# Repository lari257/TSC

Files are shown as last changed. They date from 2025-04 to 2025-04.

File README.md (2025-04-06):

### Florea Larisa - 333CA

# eBook Reader

## Diagrama Bloc

[Diagrama](https://www.mermaidchart.com/raw/8d10b74d-7767-4ccb-a096-3764c8156505?theme=light&version=v0.1&format=svg)

## Bill Of Materials (BOM)

| Part | Value | Device | Footprint Name | Detailed Description | CHECK_PRICES | DATASHEET |
|---|---|---|---|---|---|---|
| C1 | 4.7uF | EAGLE-LTSPICE_CC0402 | EAGLE-LTSPICE_C0402 | CAPACITOR, European symbol | [Link](https://ro.mouser.com/ProductDetail/EPCOS-TDK/B72520T0350K062?qs=dEfas%2FXlABIszF52uu7vrg%3D%3D) | nan |
| C1_BAT2 | 4.7uF | EAGLE-LTSPICE_CC0402 | EAGLE-LTSPICE_C0402 | CAPACITOR, European symbol | [Link](https://ro.mouser.com/ProductDetail/EPCOS-TDK/B72520T0350K062?qs=dEfas%2FXlABIszF52uu7vrg%3D%3D) | nan |
| C2 | 100nF | ESP32_WROVER_EAGLE-LTSPICE_CC0402 | ESP32_WROVER_EAGLE-LTSPICE_C0402 | CAPACITOR, European symbol | [Link](https://componentsearchengine.com/part-view/CC0402MRX5R5BB106/YAGEO) | nan |
| C2_BAT | 4.7uF | ESP32_WROVER_EAGLE-LTSPICE_CC0402 | ESP32_WROVER_EAGLE-LTSPICE_C0402 | CAPACITOR, European symbol | [Link](https://componentsearchengine.com/part-view/CC0402MRX5R5BB106/YAGEO) | nan |
| C3 | 100uF TANT | RCL_CPOL-EUCT3528 | RCL_CT3528 | POLARIZED CAPACITOR, European symbol | [Link](https://eu.mouser.com/ProductDetail/KYOCERA-AVX/F910J107MBAAJ6?qs=PqoDHHvF649LraCA%2FjeGXg%3D%3D) | [datasheet](https://ro.mouser.com/datasheet/2/40/F91_AJ6-3162641.pdf) |
| C4 | 4.7uF/25V | ESP32_WROVER_EAGLE-LTSPICE_CC0402 | ESP32_WROVER_EAGLE-LTSPICE_C0402 | CAPACITOR, European symbol | [Link](https://componentsearchengine.com/part-view/CC0402MRX5R5BB106/YAGEO) | nan |
| C4_USB | 100nF | ESP32_WROVER_EAGLE-LTSPICE_CC0402 | ESP32_WROVER_EAGLE-LTSPICE_C0402 | CAPACITOR, European symbol | [Link](https://componentsearchengine.com/part-view/CC0402MRX5R5BB106/YAGEO) | nan |
| C5 | 1uF | ESP32_WROVER_EAGLE-LTSPICE_CC0402 | ESP32_WROVER_EAGLE-LTSPICE_C0402 | CAPACITOR, European symbol | [Link](https://componentsearchengine.com/part-view/CC0402MRX5R5BB106/YAGEO) | nan |
| C5_USB | 4.7uF | ESP32_WROVER_EAGLE-LTSPICE_CC0402 | ESP32_WROVER_EAGLE-LTSPICE_C0402 | CAPACITOR, European symbol | [Link](https://componentsearchengine.com/part-view/CC0402MRX5R5BB106/YAGEO) | nan |
| C6 | 100nF | ESP32_WROVER_EAGLE-LTSPICE_CC0402 | ESP32_WROVER_EAGLE-LTSPICE_C0402 | CAPACITOR, European symbol | [Link](https://componentsearchengine.com/part-view/CC0402MRX5R5BB106/YAGEO) | nan |
| C7 | 10uF | ESP32_WROVER_EAGLE-LTSPICE_CC0402 | ESP32_WROVER_EAGLE-LTSPICE_C0402 | CAPACITOR, European symbol | [Link](https://componentsearchengine.com/part-view/CC0402MRX5R5BB106/YAGEO) | nan |
| C8 | 100nF | ESP32_WROVER_EAGLE-LTSPICE_CC0402 | ESP32_WROVER_EAGLE-LTSPICE_C0402 | CAPACITOR, European symbol | [Link](https://componentsearchengine.com/part-view/CC0402MRX5R5BB106/YAGEO) | nan |
| C9 | 100nF | EAGLE-LTSPICE_CC0402 | EAGLE-LTSPICE_C0402 | CAPACITOR, European symbol | [Link](https://ro.mouser.com/ProductDetail/EPCOS-TDK/B72520T0350K062?qs=dEfas%2FXlABIszF52uu7vrg%3D%3D) | nan |
| C10 | 100nF | ESP32_WROVER_EAGLE-LTSPICE_CC0402 | ESP32_WROVER_EAGLE-LTSPICE_C0402 | CAPACITOR, European symbol | [Link](https://componentsearchengine.com/part-view/CC0402MRX5R5BB106/YAGEO) | nan |
| C10_SUPERCAP | CPH3225A | CPH3225A | CAPCP3225X100N | Cap 0.011F 3.3V 1210 Flat Check availability | [Link](https://www.snapeda.com/parts/CPH3225A/Seiko+Instruments/view-part/?ref=eda) | [datasheet](https://www.snapeda.com/parts/CPH3225A/Seiko%20Instruments/datasheet/) |
| CHANGE_BUTTON| BUTTON_CUSYOMV1 | BUTTON_CUSYOMV1 | MYBUTTON | nan | [Link](https://industry.panasonic.com/global/en/products/control/switch/light-touch/number/evqpuj02k) | [datasheet](https://industry.panasonic.com/global/en/downloads?tab=catalog&small_g_cd=203&part_no=EVQPUJ02K) |
| CHG_LED | nan | ADAFRUIT_LEDCHIP-LED0603 | ADAFRUIT_CHIP-LED0603 | LED | [Link](https://www.snapeda.com/parts/KP-1608SURCK/Kingbright/view-part/?ref=eda) | [datasheet](https://www.snapeda.com/parts/KP-1608SURCK/Kingbright/datasheet/) |
| C_DELAY | 100nF | ESP32_WROVER_EAGLE-LTSPICE_CC0402 | ESP32_WROVER_EAGLE-LTSPICE_C0402 | CAPACITOR, European symbol | [Link](https://componentsearchengine.com/part-view/CC0402MRX5R5BB106/YAGEO) | nan |
| D1 | USBLC6-2SC6Y | USBLC6-2SC6Y | SOT95P280X145-6N | Low Cap. ESD Protection Auto SOT-23-6 STMicroelectronics USBLC6-2SC6Y, Dual Uni-Directional TVS Diode Array, 6-Pin SOT-23 | [Link](https://www.snapeda.com/parts/USBLC6-2SC6Y/STMicroelectronics/view-part/?ref=eda) | [datasheet](https://www.snapeda.com/parts/USBLC6-2SC6Y/STMicroelectronics/datasheet/) |
| D2 | ESP32_WROVER_AVX---SD0805S020S1R0_AVX_SD0805S020S1R0_0_0AVX_SD0805S020S1R0_0_0 | ESP32_WROVER_AVX---SD0805S020S1R0_AVX_SD0805S020S1R0_0_0AVX_SD0805S020S1R0_0_0 | ESP32_WROVER_AVX---SD0805S020S1R0_AVX_SD0805S020S1R0_0 | Schottky Barrier Rectifier Diode | [Link](https://eu.mouser.com/ProductDetail/KYOCERA-AVX/SD0805S020S1R0?qs=jCA%252BPfw4LHbpkAoSnwrdjw%3D%3D) | [datasheet](http://datasheets.avx.com/schottky.pdf) |
| D3 | MBR0530 | MBR0530 | SOD3716X135N | ON SEMICONDUCTOR - MBR0530 - DIODE, SCHOTTKY, 0.5A, 30V, SOD-123 | [Link](https://eu.mouser.com/ProductDetail/KYOCERA-AVX/SD0805S020S1R0?qs=jCA%252BPfw4LHbpkAoSnwrdjw%3D%3D) | [datasheet](https://ro.mouser.com/datasheet/2/40/schottky-3165252.pdf) |
| D4 | MBR0530 | MBR0530 | SOD3716X135N | ON SEMICONDUCTOR - MBR0530 - DIODE, SCHOTTKY, 0.5A, 30V, SOD-123 | [Link](https://www.snapeda.com/parts/MBR0530/Onsemi/view-part/?ref=eda) | [datasheet](https://www.snapeda.com/parts/MBR0530/ON%20Semiconductor/datasheet/) |
| D5 | MBR0530 | MBR0530 | SOD3716X135N | ON SEMICONDUCTOR - MBR0530 - DIODE, SCHOTTKY, 0.5A, 30V, SOD-123 | [Link](https://www.snapeda.com/parts/MBR0530/Onsemi/view-part/?ref=eda) | [datasheet](https://www.snapeda.com/parts/MBR0530/ON%20Semiconductor/datasheet/) |
| D6 | PGB1010603MR | PGB1010603MR | DIOC1608X36N | Check availability | [Link](https://www.snapeda.com/parts/PGB1010603MR/Littelfuse/view-part/?ref=eda) | [datasheet](https://www.snapeda.com/parts/PGB1010603MR/Littelfuse%20Inc./datasheet/) |
| D7 | ESP32_WROVER_AVX---SD0805S020S1R0_AVX_SD0805S020S1R0_0_0AVX_SD0805S020S1R0_0_0 | ESP32_WROVER_AVX---SD0805S020S1R0_AVX_SD0805S020S1R0_0_0AVX_SD0805S020S1R0_0_0 | ESP32_WROVER_AVX---SD0805S020S1R0_AVX_SD0805S020S1R0_0 | Schottky Barrier Rectifier Diode | [Link](https://eu.mouser.com/ProductDetail/KYOCERA-AVX/SD0805S020S1R0?qs=jCA%252BPfw4LHbpkAoSnwrdjw%3D%3D) | [datasheet](http://datasheets.avx.com/schottky.pdf) |
| D8 | PGB1010603MR | PGB1010603MR | DIOC1608X36N | Check availability | [Link](https://www.snapeda.com/parts/PGB1010603MR/Littelfuse/view-part/?ref=eda) | [datasheet](https://www.snapeda.com/parts/PGB1010603MR/Littelfuse%20Inc./datasheet/) |
| D9 | PGB1010603MR | PGB1010603MR | DIOC1608X36N | Check availability | [Link](https://www.snapeda.com/parts/PGB1010603MR/Littelfuse/view-part/?ref=eda) | [datasheet](https://www.snapeda.com/parts/PGB1010603MR/Littelfuse%20Inc./datasheet/) |
| D10 | PGB1010603MR | PGB1010603MR | DIOC1608X36N | Check availability | [Link](https://www.snapeda.com/parts/PGB1010603MR/Littelfuse/view-part/?ref=eda) | [datasheet](https://www.snapeda.com/parts/PGB1010603MR/Littelfuse%20Inc./datasheet/) |
| D11 | PGB1010603MR | PGB1010603MR | DIOC1608X36N | Check availability | [Link](https://www.snapeda.com/parts/PGB1010603MR/Littelfuse/view-part/?ref=eda) | [datasheet](https://www.snapeda.com/parts/PGB1010603MR/Littelfuse%20Inc./datasheet/) |
| D12 | PGB1010603MR | PGB1010603MR | DIOC1608X36N | Check availability | [Link](https://www.snapeda.com/parts/PGB1010603MR/Littelfuse/view-part/?ref=eda) | [datasheet](https://www.snapeda.com/parts/PGB1010603MR/Littelfuse%20Inc./datasheet/) |
| EPD_C1 | 1uF/50V | ESP32_WROVER_EAGLE-LTSPICE_CC0402 | ESP32_WROVER_EAGLE-LTSPICE_C0402 | CAPACITOR, European symbol | [Link](https://componentsearchengine.com/part-view/CC0402MRX5R5BB106/YAGEO) | [datasheet](http://datasheets.avx.com/schottky.pdf) |
| EPD_C2 | 1uF/50V | ESP32_WROVER_EAGLE-LTSPICE_CC0402 | ESP32_WROVER_EAGLE-LTSPICE_C0402 | CAPACITOR, European symbol | [Link](https://componentsearchengine.com/part-view/CC0402MRX5R5BB106/YAGEO) | [datasheet](http://datasheets.avx.com/schottky.pdf) |
| EPD_C5 | 1uF/50V | ESP32_WROVER_EAGLE-LTSPICE_CC0402 | ESP32_WROVER_EAGLE-LTSPICE_C0402 | CAPACITOR, European symbol | [Link](https://componentsearchengine.com/part-view/CC0402MRX5R5BB106/YAGEO) | [datasheet](http://datasheets.avx.com/schottky.pdf) |
| EPD_C6 | 1uF/50V | ESP32_WROVER_EAGLE-LTSPICE_CC0402 | ESP32_WROVER_EAGLE-LTSPICE_C0402 | CAPACITOR, European symbol | [Link](https://componentsearchengine.com/part-view/CC0402MRX5R5BB106/YAGEO) | [datasheet](http://datasheets.avx.com/schottky.pdf) |
| EPD_C7 | 1uF/50V | ESP32_WROVER_EAGLE-LTSPICE_CC0402 | ESP32_WROVER_EAGLE-LTSPICE_C0402 | CAPACITOR, European symbol | [Link](https://componentsearchengine.com/part-view/CC0402MRX5R5BB106/YAGEO) | [datasheet](http://datasheets.avx.com/schottky.pdf) |
| EPD_C8 | 1uF/50V | ESP32_WROVER_EAGLE-LTSPICE_CC0402 | ESP32_WROVER_EAGLE-LTSPICE_C0402 | CAPACITOR, European symbol | [Link](https://componentsearchengine.com/part-view/CC0402MRX5R5BB106/YAGEO) | [datasheet](http://datasheets.avx.com/schottky.pdf) |
| EPD_C9 | 1uF/50V | ESP32_WROVER_EAGLE-LTSPICE_CC0402 | ESP32_WROVER_EAGLE-LTSPICE_C0402 | CAPACITOR, European symbol | [Link](https://componentsearchengine.com/part-view/CC0402MRX5R5BB106/YAGEO) | [datasheet](http://datasheets.avx.com/schottky.pdf) |
| EPD_C10 | 1uF/50V | ESP32_WROVER_EAGLE-LTSPICE_CC0402 | ESP32_WROVER_EAGLE-LTSPICE_C0402 | CAPACITOR, European symbol | [Link](https://componentsearchengine.com/part-view/CC0402MRX5R5BB106/YAGEO) | [datasheet](http://datasheets.avx.com/schottky.pdf) |
| EPD_C11 | 1uF/50V | ESP32_WROVER_EAGLE-LTSPICE_CC0402 | ESP32_WROVER_EAGLE-LTSPICE_C0402 | CAPACITOR, European symbol | [Link](https://componentsearchengine.com/part-view/CC0402MRX5R5BB106/YAGEO) | [datasheet](http://datasheets.avx.com/schottky.pdf) |
| EPD_C12 | 1uF/50V | ESP32_WROVER_EAGLE-LTSPICE_CC0402 | ESP32_WROVER_EAGLE-LTSPICE_C0402 | CAPACITOR, European symbol | [Link](https://componentsearchengine.com/part-view/CC0402MRX5R5BB106/YAGEO) | [datasheet](http://datasheets.avx.com/schottky.pdf) |
| IC1 | BD5229G-TR | BD5229G-TR | SOT95P280X125-5N | Voltage Detector with Adjustable Delay Time: CMOS reset IC, low current consumption, Nch Open Drain and CMOS output types | [Link](https://componentsearchengine.com/part-view/BD5229G-TR/ROHM%20Semiconductor) | [datasheet](https://analytics.supplyframe.com/trackingservlet/track/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) |
| IC4 | XC6220A331MR-G | XC6220A331MR-G | SOT95P280X120-5N | LDO Voltage Regulators | [Link](https://componentsearchengine.com/part-view/XC6220A331MR-G/Torex) | [datasheet](https://analytics.supplyframe.com/trackingservlet/track/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) |
| J1 | FH34SRJ-24S-0.5SH_99_ | FH34SRJ-24S-0.5SH_99_ | FH34SRJ24S05SH99 | 24 Position FFC, FPC Connector Contacts, Top and Bottom 0.020 (0.50mm) Surface Mount, Right Angle | [Link](https://componentsearchengine.com/part-view/XC6220A331MR-G/Torex) | [datasheet](https://analytics.supplyframe.com/trackingservlet/track/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) |
| J2 | SAMACSYS_PARTS_USB4110-GF-A | SAMACSYS_PARTS_USB4110-GF-A | SAMACSYS_PARTS_USB4110GFA | CONN USB 2.0 TYPE-C R/A SMT | [Link](https://componentsearchengine.com/part-view/USB4110-GF-A/GCT%20(GLOBAL%20CONNECTOR%20TECHNOLOGY)) | [datasheet](https://analytics.supplyframe.com/trackingservlet/track/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) |
| J3 | QWIIC_RIGHT_ANGLE | QWIIC_CONNECTORJS-1MM | JST04_1MM_RA | SparkFun I2C Standard Qwiic Connector | [Link](4208%20Adafruit%20\|%20Mouser) | [datasheet](https://www.armega.com.tr/datasheet/4208-adafruit-industries-llc-datasheet-7323652) |
| J4 | 112A-TAAR-R03_ATTEND | 112A-TAAR-R03_ATTEND | 112ATAARR03ATTEND | Micro SD Card Socket, Push-Push Type, Top Mount, SMT, H=1.83mm, 10u | [Link](https://store.comet.srl.ro/Catalogue/Product/43497/) | [datasheet](https://store.comet.bg/download-file.php?id=8824) |
| L1 | 68uH | 744043680IND_4828-WE-TPC_WRE | IND_4828-WE-TPC_WRE | nan | [Link](https://eu.mouser.com/ProductDetail/Wurth-Elektronik/744043680?qs=PGXP4M47uW6VkZq%252BkzjrHA%3D%3D) | [datasheet](https://www.we-online.com/components/products/datasheet/744043680.pdf) |
| PFMF.050.1 | ESP32C6_VARISTORCN1812 | ESP32C6_VARISTORCN1812 | ESP32C6_VARISTOR_CT/CN1812 | VARISTOR | [Link](https://www.mouser.co.uk/ProductDetail/EPCOS-TDK/B72520T0350K062?qs=dEfas%2FXlABIszF52uu7vrg%3D%3D) | [datasheet](https://www.tdk-electronics.tdk.com/inf/75/db/CTVS_14/Surge_protection_series.pdf) |
| Q1 | 20V/4.2A/52mO/1.4W | ESP32_WROVER_SPARKFUN-DISCRETESEMI_MOSFET_PCH-DMG2305UX-7 | ESP32_WROVER_SPARKFUN-DISCRETESEMI_SOT23-3 | P-channel MOSFETs | [Link](https://componentsearchengine.com/part-view/DMG2305UX-7/Diodes%20Incorporated) | [datasheet](https://analytics.supplyframe.com/trackingservlet/track/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) |
| Q2 | 20V/4.2A/52mO/1.4W | ESP32_WROVER_SPARKFUN-DISCRETESEMI_MOSFET_PCH-DMG2305UX-7 | ESP32_WROVER_SPARKFUN-DISCRETESEMI_SOT23-3 | P-channel MOSFETs | [Link]() | nan |
| Q3 | SI1308EDL-T1-GE3 | D8 | SOT65P210X110-3N | MOSFET N-Ch 30V 1.5A TrenchFET SC70 Vishay Si1308EDL-T1-GE3 N-channel MOSFET Transistor, 1.5 A, 30 V, 3-Pin SC-70 | [Link](https://componentsearchengine.com/part-view/SI1308EDL-T1-GE3/Vishay) | [datasheet](https://analytics.supplyframe.com/trackingservlet/track/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) |
| R1 | 10K | ESP32_WROVER_EAGLE-LTSPICE_RR0402 | ESP32_WROVER_EAGLE-LTSPICE_R0402 | RESISTOR, European symbol | [Link](https://componentsearchengine.com/part-view/CC0402MRX5R5BB106/YAGEO) | [datasheet](http://datasheets.avx.com/schottky.pdf) |
| R1-PINH | 10K | ESP32_WROVER_EAGLE-LTSPICE_RR0402 | ESP32_WROVER_EAGLE-LTSPICE_R0402 | RESISTOR, European symbol | [Link](https://componentsearchengine.com/part-view/CC0402MRX5R5BB106/YAGEO) | [datasheet](http://datasheets.avx.com/schottky.pdf) |
| R1-PINH1 | 10K | ESP32_WROVER_EAGLE-LTSPICE_RR0402 | ESP32_WROVER_EAGLE-LTSPICE_R0402 | RESISTOR, European symbol | [Link](https://componentsearchengine.com/part-view/CC0402MRX5R5BB106/YAGEO) | [datasheet](http://datasheets.avx.com/schottky.pdf) |
| R1_BAT | 200 | ESP32_WROVER_EAGLE-LTSPICE_RR0402 | ESP32_WROVER_EAGLE-LTSPICE_R0402 | RESISTOR, European symbol | [Link](https://componentsearchengine.com/part-view/CC0402MRX5R5BB106/YAGEO) | [datasheet](http://datasheets.avx.com/schottky.pdf) |
| R1_PWRUSB | 100K | ESP32_WROVER_EAGLE-LTSPICE_RR0402 | ESP32_WROVER_EAGLE-LTSPICE_R0402 | RESISTOR, European symbol | [Link](https://componentsearchengine.com/part-view/CC0402MRX5R5BB106/YAGEO) | [datasheet](http://datasheets.avx.com/schottky.pdf) |
| R2 | 2.2 | ESP32_WROVER_EAGLE-LTSPICE_RR0402 | ESP32_WROVER_EAGLE-LTSPICE_R0402 | RESISTOR, European symbol | [Link](https://componentsearchengine.com/part-view/R0402%201%25%20100%20K%20(RC0402FR-07100KL)/YAGEO) | [datasheet](https://analytics.supplyframe.com/trackingservlet/track/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) |
| R2-PINH | 10K | ESP32_WROVER_EAGLE-LTSPICE_RR0402 | ESP32_WROVER_EAGLE-LTSPICE_R0402 | RESISTOR, European symbol | [Link](https://componentsearchengine.com/part-view/CC0402MRX5R5BB106/YAGEO) | [datasheet](http://datasheets.avx.com/schottky.pdf) |
| R2-PINH1 | 10K | ESP32_WROVER_EAGLE-LTSPICE_RR0402 | ESP32_WROVER_EAGLE-LTSPICE_R0402 | RESISTOR, European symbol | [Link](https://componentsearchengine.com/part-view/CC0402MRX5R5BB106/YAGEO) | [datasheet](http://datasheets.avx.com/schottky.pdf) |
| R2-USB | 5k1 | ESP32_WROVER_EAGLE-LTSPICE_RR0402 | ESP32_WROVER_EAGLE-LTSPICE_R0402 | RESISTOR, European symbol | [Link](https://componentsearchengine.com/part-view/CC0402MRX5R5BB106/YAGEO) | [datasheet](http://datasheets.avx.com/schottky.pdf) |
| R2-USB1 | 5k1 | ESP32_WROVER_EAGLE-LTSPICE_RR0402 | ESP32_WROVER_EAGLE-LTSPICE_R0402 | RESISTOR, European symbol | [Link](https://componentsearchengine.com/part-view/CC0402MRX5R5BB106/YAGEO) | [datasheet](http://datasheets.avx.com/schottky.pdf) |
| R2_BAT | 2K | ESP32_WROVER_EAGLE-LTSPICE_RR0402 | ESP32_WROVER_EAGLE-LTSPICE_R0402 | RESISTOR, European symbol | [Link](https://componentsearchengine.com/part-view/CC0402MRX5R5BB106/YAGEO) | [datasheet](http://datasheets.avx.com/schottky.pdf) |
| R3 | 10K | ESP32_WROVER_EAGLE-LTSPICE_RR0402 | ESP32_WROVER_EAGLE-LTSPICE_R0402 | RESISTOR, European symbol | [Link](https://componentsearchengine.com/part-view/CC0402MRX5R5BB106/YAGEO) | [datasheet](http://datasheets.avx.com/schottky.pdf) |
| R4 | 10K | ESP32_WROVER_EAGLE-LTSPICE_RR0402 | ESP32_WROVER_EAGLE-LTSPICE_R0402 | RESISTOR, European symbol | [Link](https://componentsearchengine.com/part-view/CC0402MRX5R5BB106/YAGEO) | [datasheet](http://datasheets.avx.com/schottky.pdf) |
| R5 | 10K | ESP32_WROVER_EAGLE-LTSPICE_RR0402 | ESP32_WROVER_EAGLE-LTSPICE_R0402 | RESISTOR, European symbol | [Link](https://componentsearchengine.com/part-view/CC0402MRX5R5BB106/YAGEO) | [datasheet](http://datasheets.avx.com/schottky.pdf) |
| R6 | 10K | ESP32_WROVER_EAGLE-LTSPICE_RR0402 | ESP32_WROVER_EAGLE-LTSPICE_R0402 | RESISTOR, European symbol | [Link](https://componentsearchengine.com/part-view/CC0402MRX5R5BB106/YAGEO) | [datasheet](http://datasheets.avx.com/schottky.pdf) |
| R7 | 10K | ESP32_WROVER_EAGLE-LTSPICE_RR0402 | ESP32_WROVER_EAGLE-LTSPICE_R0402 | RESISTOR, European symbol | [Link](https://componentsearchengine.com/part-view/CC0402MRX5R5BB106/YAGEO) | [datasheet](http://datasheets.avx.com/schottky.pdf) |
| R8 | 10K | ESP32_WROVER_EAGLE-LTSPICE_RR0402 | ESP32_WROVER_EAGLE-LTSPICE_R0402 | RESISTOR, European symbol | [Link](https://componentsearchengine.com/part-view/CC0402MRX5R5BB106/YAGEO) | [datasheet](http://datasheets.avx.com/schottky.pdf) |
| R9 | 10K | ESP32_WROVER_EAGLE-LTSPICE_RR0402 | ESP32_WROVER_EAGLE-LTSPICE_R0402 | RESISTOR, European symbol | [Link](https://componentsearchengine.com/part-view/CC0402MRX5R5BB106/YAGEO) | [datasheet](http://datasheets.avx.com/schottky.pdf) |
| R10 | 10K | ESP32_WROVER_EAGLE-LTSPICE_RR0402 | ESP32_WROVER_EAGLE-LTSPICE_R0402 | RESISTOR, European symbol | [Link](https://componentsearchengine.com/part-view/CC0402MRX5R5BB106/YAGEO) | [datasheet](http://datasheets.avx.com/schottky.pdf) |
| RESET_BUTTON | BUTTON_CUSYOMV1 | BUTTON_CUSYOMV1 | MYBUTTON | nan | [Link](https://industry.panasonic.com/global/en/products/control/switch/light-touch/number/evqpuj02k) | [datasheet](https://industry.panasonic.com/global/en/downloads?tab=catalog&small_g_cd=203&part_no=EVQPUJ02K) |
| R_BOOT | 10K | ESP32_WROVER_EAGLE-LTSPICE_RR0402 | ESP32_WROVER_EAGLE-LTSPICE_R0402 | RESISTOR, European symbol | [Link](https://componentsearchengine.com/part-view/CC0402MRX5R5BB106/YAGEO) | [datasheet](http://datasheets.avx.com/schottky.pdf) |
| R_CAPACITOR  | 15 | ESP32_WROVER_EAGLE-LTSPICE_RR0402 | ESP32_WROVER_EAGLE-LTSPICE_R0402 | RESISTOR, European symbol | [Link](https://componentsearchengine.com/part-view/CC0402MRX5R5BB106/YAGEO) | [datasheet](http://datasheets.avx.com/schottky.pdf) |
| R_CHANGE | 10K | ESP32_WROVER_EAGLE-LTSPICE_RR0402 | ESP32_WROVER_EAGLE-LTSPICE_R0402 | RESISTOR, European symbol | [Link](https://componentsearchengine.com/part-view/CC0402MRX5R5BB106/YAGEO) | [datasheet](http://datasheets.avx.com/schottky.pdf) |
| R_CL1 | 10K | ESP32_WROVER_EAGLE-LTSPICE_RR0402 | ESP32_WROVER_EAGLE-LTSPICE_R0402 | RESISTOR, European symbol | [Link](https://componentsearchengine.com/part-view/CC0402MRX5R5BB106/YAGEO) | [datasheet](http://datasheets.avx.com/schottky.pdf) |
| R_RESET | 10K | ESP32_WROVER_EAGLE-LTSPICE_RR0402 | ESP32_WROVER_EAGLE-LTSPICE_R0402 | RESISTOR, European symbol | [Link](https://componentsearchengine.com/part-view/CC0402MRX5R5BB106/YAGEO) | [datasheet](http://datasheets.avx.com/schottky.pdf) |
| SENSOR2 | ESP32_WROVER_BME680_BME680 | ESP32_WROVER_BME680_BME680 | ESP32_WROVER_BME680_PSON80P300X300X100-8N  | Integrated Environmental Unit | [Link](https://www.snapeda.com/parts/BME680/Bosch/view-part/?welcome=home) | [datasheet](https://www.snapeda.com/parts/BME680/Bosch%20Sensortec/datasheet/) |
| SJ1 | SJ | SJ | SJ | SMD solder JUMPER | [Link](https://grabcad.com/library/solder-jumpers-1) | nan |
| U1 | W25Q512JVEIQ | W25Q512JVEIQ | SON127P600X800X80-9N | Check availability | [Link](https://www.snapeda.com/parts/W25Q512JVEIQ/Winbond+Electronics/view-part/?ref=eda) | [datasheet](https://www.snapeda.com/parts/W25Q512JVEIQ/Winbond%20Electronics/datasheet/) |
| U2 | ESP32-C6-WROOM-1-N8 | ESP32-C6-WROOM-1-N8 | XCVR_ESP32-C6-WROOM-1-N8 | Check availability | [Link](https://www.snapeda.com/parts/ESP32-C6-WROOM-1-N8/Espressif+Systems/view-part/?ref=eda) | [datasheet](https://www.snapeda.com/parts/ESP32-C6-WROOM-1-N8/Espressif%20Systems/datasheet/) |
| U3 | DS3231SN# | DS3231SN# | SOIC127P1032X265-16N | Real Time Clock Serial 16-Pin SOIC W T/R Check availability | [Link](https://www.snapeda.com/parts/DS3231SN%23/Analog+Devices/view-part/?ref=eda) | [datasheet](https://www.snapeda.com/parts/DS3231SN%23/Analog%20Devices/datasheet/) |
| U4 | MAX17048G+T10 | MAX17048G+T10 | SON50P200X200X80-9N | Check availability | [Link](https://www.snapeda.com/parts/MAX17048G+T10/Analog+Devices/view-part/?ref=eda) | [datasheet](https://www.snapeda.com/parts/MAX17048G+T10/Analog%20Devices/datasheet/) |
| U5 | MCP73831 | ESP32_WROVER_SPARKFUN-IC-POWER_MCP73831 | ESP32_WROVER_SPARKFUN-IC-POWER_SOT23-5 | MCP73831T Li-Ion, Li-Pol Controller | [Link](https://eu.mouser.com/ProductDetail/Microchip-Technology/MCP73831T-2ACI-OT?qs=yUQqVecv4qvbBQBGbHx0Mw%3D%3D) | [datasheet](https://ro.mouser.com/datasheet/2/268/MCP73831_Family_Data_Sheet_DS20001984H-3441711.pdf) |

## Detalii tehnice ale sistemului hardware

### Componente și funcții principale

- **Microcontroler ESP32-C6-WROOM-1-N8**
  - **Funcție:** Control central, procesarea datelor, comunicare wireless (Wi-Fi și Bluetooth), gestionare periferice.
  - **Interfețe suportate:** SPI, I²C, UART, ADC, PWM.

- **Memorie NOR Flash (W25Q512JVEIQ - 64MB)**
  - **Funcție:** Stocarea permanentă a firmware-ului și a datelor utilizatorului.
  - **Conectare:** Protocol SPI pentru transfer rapid și sigur al datelor.

- **Display E-Paper (Circuit driver integrat)**
  - **Funcție:** Afișare eficientă energetic a conținutului text și grafic.
  - **Conectare:** Interfață SPI cu linii adiționale dedicate pentru comandă (DC) și reset (RST).

- **Real Time Clock (DS3231SN)**
  - **Funcție:** Păstrează ora exactă independent de alimentarea principală.
  - **Conectare:** Magistrală I²C pentru integrare simplă și economisirea pinilor.

- **Senzor ambiental (BME688)**
  - **Funcție:** Măsurare parametri ambientali (temperatură, umiditate, presiune, compuși organici volatili - VOC).
  - **Conectare:** Magistrală I²C.

- **Monitor încărcare baterie (MAX17048)**
  - **Funcție:** Monitorizează precis starea și nivelul bateriei.
  - **Conectare:** Interfață I²C.

- **Circuit încărcare baterie (MCP73831)**
  - **Funcție:** Gestionează încărcarea sigură a bateriilor Li-Po.
  - **Conectare:** Direct la circuitul de alimentare și la bateria Li-Po.

- **Modul regulator LDO (XC6220A331MR-G)**
  - **Funcție:** Stabilizează tensiunea de alimentare la 3.3V pentru toate componentele sistemului.

- **Protecție și management USB**
  - **Funcție:** Alimentarea și protecția electrostatică (ESD) prin interfața USB-C.

### Alocarea și utilizarea pinilor ESP32-C6

#### SPI (Interfață rapidă pentru periferice)
- **Flash NOR W25Q512JVEIQ:** MOSI, MISO, SCK, CS (pentru transfer rapid date)
- **Display E-Paper:** MOSI, SCK, CS, DC, RST (control și afișare)
- **Modul Card SD:** MOSI, MISO, SCK, CS (stocare suplimentară)

#### I²C (Magistrală periferice standard)
- **BME688, DS3231SN, MAX17048:** SDA, SCL (optimizare pini, integrare facilă)
- **Interfață Qwiic/Stemma QT:** SDA, SCL (extindere rapidă cu senzori adiționali)

#### UART (Comunicație și debugging)
- **TX și RX:** GPIO-uri dedicate pentru comunicare serială și debugging

#### Funcții adiționale (GPIO-uri dedicate)
- **Buton reset/manual:** Intrare digitală pentru reset sau control utilizator
- **LED indicator:** Ieșire digitală pentru feedback vizual al stării sistemului

#### Conectare USB și alimentare
- **Port USB-C:** Programare firmware, debugging, alimentare și protecție ESD

### Raționament pentru selecția pinilor

- **SPI:** Permite comunicare rapidă și sigură, optimizată pentru transfer date către periferice critice (display și memorie externă).
- **I²C:** Utilizează o singură magistrală pentru conectarea simultană a mai multor senzori și dispozitive, reducând complexitatea cablajului.
- **UART:** Esențială pentru depanare și monitorizare, simplificând dezvoltarea și întreținerea.
- **GPIO-uri:** Alocate logic pentru control simplu și accesibil al elementelor interactive (butoane, LED-uri).
- **USB:** Facilitează o alimentare stabilă și flexibilă, și permite depanarea simplă și eficientă.

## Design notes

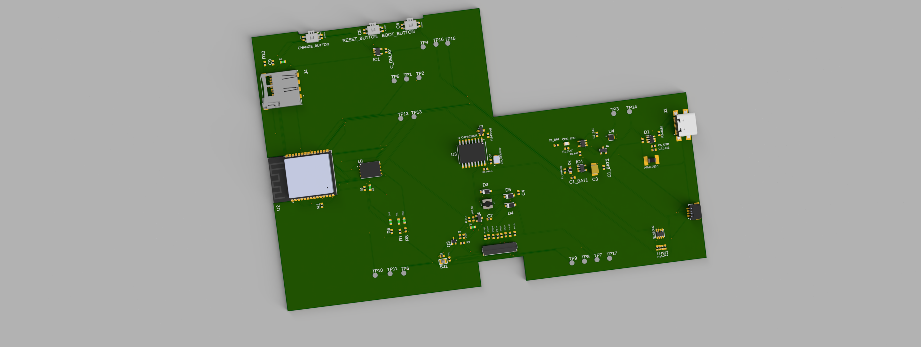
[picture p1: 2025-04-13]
Images/Board Image.png

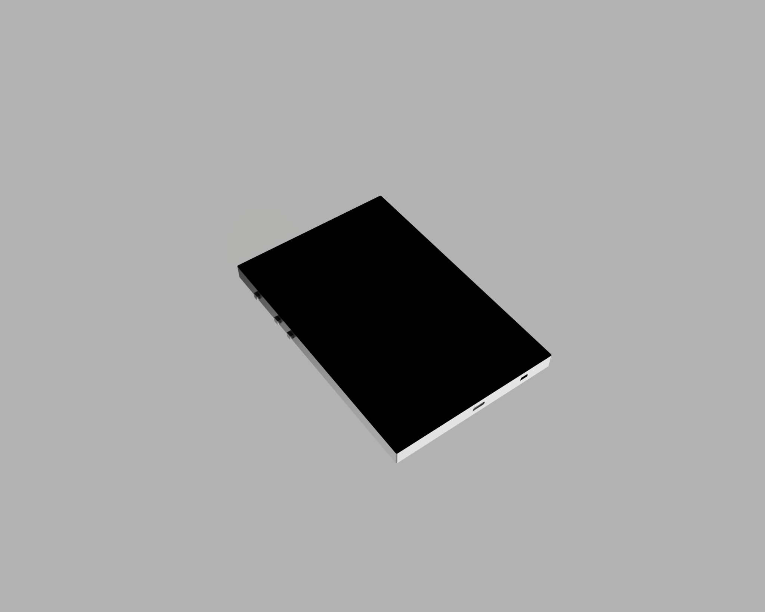
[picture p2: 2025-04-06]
Images/ebook.png

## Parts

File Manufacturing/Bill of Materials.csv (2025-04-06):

Part | Value | Device | Package | Description | 68UH | ARROW_PART_NUMBER | ARROW_PRICE-STOCK | AVAILABILITY | BME688 | CENTROID_NOT_SPECIFIED | CHECK_PRICES | COPYRIGHT | DATASHEET | DESCRIPTION | DIGIKEY_DESCRIPTION | DIGIKEY_PART_NUMBER | DMG2305UX-7 | HEIGHT | LEAD_FREE | MANUFACTURER_NAME | MANUFACTURER_PART_NUMBER | MF | MFR_NAME | MOUSER_PART_NUMBER | MOUSER_PRICE-STOCK | MOUSER_TESTING_PART_NUMBER | MOUSER_TESTING_PRICE-STOCK | MP | MPN | PACKAGE | POPULARITY | PREFIX | PRICE | PROD_ID | PURCHASE-URL | ROHS | SD0805S020S1R0 | SNAPEDA_LINK | SPICEMODEL | SPICEPREFIX | TEMPERATURE_RANGE_HIGH | TEMPERATURE_RANGE_LOW | TP_SIGNAL_NAME | VALUE
BOOT_BUTTON | BUTTON_CUSYOMV1 | BUTTON_CUSYOMV1 | MYBUTTON
C1 | 100nF | EAGLE-LTSPICE_CC0402 | EAGLE-LTSPICE_C0402 | CAPACITOR, European symbol |  |  |  |  |  |  |  |  |  |  |  |  |  |  |  |  |  |  |  |  |  |  |  |  |  |  |  |  |  |  |  |  |  |  | NONE | C
C1_BAT | 4.7uF | EAGLE-LTSPICE_CC0402 | EAGLE-LTSPICE_C0402 | CAPACITOR, European symbol |  |  |  |  |  |  |  |  |  |  |  |  |  |  |  |  |  |  |  |  |  |  |  |  |  |  |  |  |  |  |  |  |  |  | NONE | C
C1_BAT1 | 4.7uF | ESP32_WROVER_EAGLE-LTSPICE_CC0402 | ESP32_WROVER_EAGLE-LTSPICE_C0402 | CAPACITOR, European symbol |  |  |  |  |  |  |  |  |  |  |  |  |  |  |  |  |  |  |  |  |  |  |  |  |  |  |  |  |  |  |  |  |  |  | NONE | C
C1_BAT2 | 4.7uF | ESP32_WROVER_EAGLE-LTSPICE_CC0402 | ESP32_WROVER_EAGLE-LTSPICE_C0402 | CAPACITOR, European symbol |  |  |  |  |  |  |  |  |  |  |  |  |  |  |  |  |  |  |  |  |  |  |  |  |  |  |  |  |  |  |  |  |  |  | NONE | C
C2 | 100nF | EAGLE-LTSPICE_CC0402 | EAGLE-LTSPICE_C0402 | CAPACITOR, European symbol |  |  |  |  |  |  |  |  |  |  |  |  |  |  |  |  |  |  |  |  |  |  |  |  |  |  |  |  |  |  |  |  |  |  | NONE | C
C2_BAT | 4.7uF | EAGLE-LTSPICE_CC0402 | EAGLE-LTSPICE_C0402 | CAPACITOR, European symbol |  |  |  |  |  |  |  |  |  |  |  |  |  |  |  |  |  |  |  |  |  |  |  |  |  |  |  |  |  |  |  |  |  |  | NONE | C
C3 | 100uF TANT | RCL_CPOL-EUCT3528 | RCL_CT3528 | POLARIZED CAPACITOR, European symbol |  |  |  |  |  |  |  |  |  |  |  |  |  |  |  |  |  |  |  |  |  |  |  |  |  |  | 0 |  |  |  |  |  |  |  |  | C
C4 | 4.7uF/25V | ESP32_WROVER_EAGLE-LTSPICE_CC0402 | ESP32_WROVER_EAGLE-LTSPICE_C0402 | CAPACITOR, European symbol |  |  |  |  |  |  |  |  |  |  |  |  |  |  |  |  |  |  |  |  |  |  |  |  |  |  |  |  |  |  |  |  |  |  | NONE | C
C4_USB | 100nF | ESP32_WROVER_EAGLE-LTSPICE_CC0402 | ESP32_WROVER_EAGLE-LTSPICE_C0402 | CAPACITOR, European symbol |  |  |  |  |  |  |  |  |  |  |  |  |  |  |  |  |  |  |  |  |  |  |  |  |  |  |  |  |  |  |  |  |  |  | NONE | C
C5 | 1uF | EAGLE-LTSPICE_CC0402 | EAGLE-LTSPICE_C0402 | CAPACITOR, European symbol |  |  |  |  |  |  |  |  |  |  |  |  |  |  |  |  |  |  |  |  |  |  |  |  |  |  |  |  |  |  |  |  |  |  | NONE | C
C5_USB | 4.7uF | ESP32_WROVER_EAGLE-LTSPICE_CC0402 | ESP32_WROVER_EAGLE-LTSPICE_C0402 | CAPACITOR, European symbol |  |  |  |  |  |  |  |  |  |  |  |  |  |  |  |  |  |  |  |  |  |  |  |  |  |  |  |  |  |  |  |  |  |  | NONE | C
C6 | 100nF | EAGLE-LTSPICE_CC0402 | EAGLE-LTSPICE_C0402 | CAPACITOR, European symbol |  |  |  |  |  |  |  |  |  |  |  |  |  |  |  |  |  |  |  |  |  |  |  |  |  |  |  |  |  |  |  |  |  |  | NONE | C
C7 | 10uF | ESP32_WROVER_EAGLE-LTSPICE_CC0402 | ESP32_WROVER_EAGLE-LTSPICE_C0402 | CAPACITOR, European symbol |  |  |  |  |  |  |  |  |  |  |  |  |  |  |  |  |  |  |  |  |  |  |  |  |  |  |  |  |  |  |  |  |  |  | NONE | C
C8 | 100nF | EAGLE-LTSPICE_CC0402 | EAGLE-LTSPICE_C0402 | CAPACITOR, European symbol |  |  |  |  |  |  |  |  |  |  |  |  |  |  |  |  |  |  |  |  |  |  |  |  |  |  |  |  |  |  |  |  |  |  | NONE | C
C9 | 100nF | EAGLE-LTSPICE_CC0402 | EAGLE-LTSPICE_C0402 | CAPACITOR, European symbol |  |  |  |  |  |  |  |  |  |  |  |  |  |  |  |  |  |  |  |  |  |  |  |  |  |  |  |  |  |  |  |  |  |  | NONE | C
C10 | 100nF | EAGLE-LTSPICE_CC0402 | EAGLE-LTSPICE_C0402 | CAPACITOR, European symbol |  |  |  |  |  |  |  |  |  |  |  |  |  |  |  |  |  |  |  |  |  |  |  |  |  |  |  |  |  |  |  |  |  |  | NONE | C
C10_SUPERCAP | CPH3225A | CPH3225A | CAPCP3225X100N | Cap 0.011F 3.3V 1210 Flat Check availability |  |  |  | Not in stock |  |  | https://www.snapeda.com/parts/CPH3225A/Seiko+Instruments/view-part/?ref=eda |  |  | 11 mF (EDLC) Supercapacitor 3.3 V 1210 (3225 Metric) - - |  |  |  |  |  |  |  | Seiko Instruments |  |  |  |  |  | CPH3225A |  | 1210 Seiko |  |  | None |  | https://www.snapeda.com/api/url_track_click_mouser/?unipart_id=562593&manufacturer=Seiko Instruments&part_name=CPH3225A&search_term=None |  |  | https://www.snapeda.com/parts/CPH3225A/Seiko+Instruments/view-part/?ref=snap
CHANGE_BUTTON | BUTTON_CUSYOMV1 | BUTTON_CUSYOMV1 | MYBUTTON
CHG_LED |  | ADAFRUIT_LEDCHIP-LED0603 | ADAFRUIT_CHIP-LED0603 | LED
C_DELAY | 100nF | EAGLE-LTSPICE_CC0402 | EAGLE-LTSPICE_C0402 | CAPACITOR, European symbol |  |  |  |  |  |  |  |  |  |  |  |  |  |  |  |  |  |  |  |  |  |  |  |  |  |  |  |  |  |  |  |  |  |  | NONE | C
D1 | USBLC6-2SC6Y | USBLC6-2SC6Y | SOT95P280X145-6N | Low Cap. ESD Protection Auto SOT-23-6 STMicroelectronics USBLC6-2SC6Y, Dual Uni-Directional TVS Diode Array, 6-Pin SOT-23 |  |  |  | In Stock |  |  | https://www.snapeda.com/parts/USBLC6-2SC6Y/STMicroelectronics/view-part/?ref=eda |  |  | 17V Clamp 5A (8/20µs) Ipp Tvs Diode Surface Mount SOT-23-6 |  |  |  |  |  |  |  | STMicroelectronics |  |  |  |  |  | USBLC6-2SC6Y |  | SOT-23-6 STMicroelectronics |  |  | None |  |  |  |  | https://www.snapeda.com/parts/USBLC6-2SC6Y/STMicroelectronics/view-part/?ref=snap
D2 | ESP32_WROVER_AVX---SD0805S020S1R0_AVX_SD0805S020S1R0_0_0AVX_SD0805S020S1R0_0_0 | ESP32_WROVER_AVX---SD0805S020S1R0_AVX_SD0805S020S1R0_0_0AVX_SD0805S020S1R0_0_0 | ESP32_WROVER_AVX---SD0805S020S1R0_AVX_SD0805S020S1R0_0 | Schottky Barrier Rectifier Diode |  |  |  |  |  | No |  |  | http://datasheets.avx.com/schottky.pdf |  | DIODE SCHOTTKY 20V 1A 0805 | 478-7800-1-ND |  |  | yes |  |  | AVX |  | 581-SD0805S020S1R0 |  |  |  |  |  | 0805 (2012 metric) |  | D |  |  |  | yes |  |  |  |  | +125°C | -55°C
D3 | MBR0530 | MBR0530 | SOD3716X135N | ON SEMICONDUCTOR - MBR0530 - DIODE, SCHOTTKY, 0.5A, 30V, SOD-123 |  |  |  | In Stock |  |  | https://www.snapeda.com/parts/MBR0530/Onsemi/view-part/?ref=eda |  |  | Diode Schottky 30 V 500mA Surface Mount SOD-123 |  |  |  |  |  |  |  | ON Semiconductor |  |  |  |  |  | MBR0530 |  | SOD-123-2 ON Semiconductor |  |  | None |  | https://www.snapeda.com/api/url_track_click_mouser/?unipart_id=179458&manufacturer=ON Semiconductor&part_name=MBR0530&search_term=None |  |  | https://www.snapeda.com/parts/MBR0530/Onsemi/view-part/?ref=snap
D4 | MBR0530 | MBR0530 | SOD3716X135N | ON SEMICONDUCTOR - MBR0530 - DIODE, SCHOTTKY, 0.5A, 30V, SOD-123 |  |  |  | In Stock |  |  | https://www.snapeda.com/parts/MBR0530/Onsemi/view-part/?ref=eda |  |  | Diode Schottky 30 V 500mA Surface Mount SOD-123 |  |  |  |  |  |  |  | ON Semiconductor |  |  |  |  |  | MBR0530 |  | SOD-123-2 ON Semiconductor |  |  | None |  | https://www.snapeda.com/api/url_track_click_mouser/?unipart_id=179458&manufacturer=ON Semiconductor&part_name=MBR0530&search_term=None |  |  | https://www.snapeda.com/parts/MBR0530/Onsemi/view-part/?ref=snap
D5 | MBR0530 | MBR0530 | SOD3716X135N | ON SEMICONDUCTOR - MBR0530 - DIODE, SCHOTTKY, 0.5A, 30V, SOD-123 |  |  |  | In Stock |  |  | https://www.snapeda.com/parts/MBR0530/Onsemi/view-part/?ref=eda |  |  | Diode Schottky 30 V 500mA Surface Mount SOD-123 |  |  |  |  |  |  |  | ON Semiconductor |  |  |  |  |  | MBR0530 |  | SOD-123-2 ON Semiconductor |  |  | None |  | https://www.snapeda.com/api/url_track_click_mouser/?unipart_id=179458&manufacturer=ON Semiconductor&part_name=MBR0530&search_term=None |  |  | https://www.snapeda.com/parts/MBR0530/Onsemi/view-part/?ref=snap
D6 | PGB1010603MR | PGB1010603MR | DIOC1608X36N | Check availability |  |  |  | In Stock |  |  | https://www.snapeda.com/parts/PGB1010603MR/Littelfuse/view-part/?ref=eda |  |  | 150V (Typ) Clamp - Ipp Tvs Diode Surface Mount 0603 (1608 Metric) |  |  |  |  |  |  |  | Littelfuse Inc. |  |  |  |  |  | PGB1010603MR |  | 0603 Littelfuse Inc. |  |  | None |  | https://www.snapeda.com/api/url_track_click_mouser/?unipart_id=5659453&manufacturer=Littelfuse Inc.&part_name=PGB1010603MR&search_term=None |  |  | https://www.snapeda.com/parts/PGB1010603MR/Littelfuse/view-part/?ref=snap
D7 | ESP32_WROVER_AVX---SD0805S020S1R0_AVX_SD0805S020S1R0_0_0AVX_SD0805S020S1R0_0_0 | ESP32_WROVER_AVX---SD0805S020S1R0_AVX_SD0805S020S1R0_0_0AVX_SD0805S020S1R0_0_0 | ESP32_WROVER_AVX---SD0805S020S1R0_AVX_SD0805S020S1R0_0 | Schottky Barrier Rectifier Diode |  |  |  |  |  | No |  |  | http://datasheets.avx.com/schottky.pdf |  | DIODE SCHOTTKY 20V 1A 0805 | 478-7800-1-ND |  |  | yes |  |  | AVX |  | 581-SD0805S020S1R0 |  |  |  |  |  | 0805 (2012 metric) |  | D |  |  |  | yes |  |  |  |  | +125°C | -55°C
D8 | PGB1010603MR | PGB1010603MR | DIOC1608X36N | Check availability |  |  |  | In Stock |  |  | https://www.snapeda.com/parts/PGB1010603MR/Littelfuse/view-part/?ref=eda |  |  | 150V (Typ) Clamp - Ipp Tvs Diode Surface Mount 0603 (1608 Metric) |  |  |  |  |  |  |  | Littelfuse Inc. |  |  |  |  |  | PGB1010603MR |  | 0603 Littelfuse Inc. |  |  | None |  | https://www.snapeda.com/api/url_track_click_mouser/?unipart_id=5659453&manufacturer=Littelfuse Inc.&part_name=PGB1010603MR&search_term=None |  |  | https://www.snapeda.com/parts/PGB1010603MR/Littelfuse/view-part/?ref=snap
D9 | PGB1010603MR | PGB1010603MR | DIOC1608X36N | Check availability |  |  |  | In Stock |  |  | https://www.snapeda.com/parts/PGB1010603MR/Littelfuse/view-part/?ref=eda |  |  | 150V (Typ) Clamp - Ipp Tvs Diode Surface Mount 0603 (1608 Metric) |  |  |  |  |  |  |  | Littelfuse Inc. |  |  |  |  |  | PGB1010603MR |  | 0603 Littelfuse Inc. |  |  | None |  | https://www.snapeda.com/api/url_track_click_mouser/?unipart_id=5659453&manufacturer=Littelfuse Inc.&part_name=PGB1010603MR&search_term=None |  |  | https://www.snapeda.com/parts/PGB1010603MR/Littelfuse/view-part/?ref=snap
D10 | PGB1010603MR | PGB1010603MR | DIOC1608X36N | Check availability |  |  |  | In Stock |  |  | https://www.snapeda.com/parts/PGB1010603MR/Littelfuse/view-part/?ref=eda |  |  | 150V (Typ) Clamp - Ipp Tvs Diode Surface Mount 0603 (1608 Metric) |  |  |  |  |  |  |  | Littelfuse Inc. |  |  |  |  |  | PGB1010603MR |  | 0603 Littelfuse Inc. |  |  | None |  | https://www.snapeda.com/api/url_track_click_mouser/?unipart_id=5659453&manufacturer=Littelfuse Inc.&part_name=PGB1010603MR&search_term=None |  |  | https://www.snapeda.com/parts/PGB1010603MR/Littelfuse/view-part/?ref=snap
D11 | PGB1010603MR | PGB1010603MR | DIOC1608X36N | Check availability |  |  |  | In Stock |  |  | https://www.snapeda.com/parts/PGB1010603MR/Littelfuse/view-part/?ref=eda |  |  | 150V (Typ) Clamp - Ipp Tvs Diode Surface Mount 0603 (1608 Metric) |  |  |  |  |  |  |  | Littelfuse Inc. |  |  |  |  |  | PGB1010603MR |  | 0603 Littelfuse Inc. |  |  | None |  | https://www.snapeda.com/api/url_track_click_mouser/?unipart_id=5659453&manufacturer=Littelfuse Inc.&part_name=PGB1010603MR&search_term=None |  |  | https://www.snapeda.com/parts/PGB1010603MR/Littelfuse/view-part/?ref=snap
D12 | PGB1010603MR | PGB1010603MR | DIOC1608X36N | Check availability |  |  |  | In Stock |  |  | https://www.snapeda.com/parts/PGB1010603MR/Littelfuse/view-part/?ref=eda |  |  | 150V (Typ) Clamp - Ipp Tvs Diode Surface Mount 0603 (1608 Metric) |  |  |  |  |  |  |  | Littelfuse Inc. |  |  |  |  |  | PGB1010603MR |  | 0603 Littelfuse Inc. |  |  | None |  | https://www.snapeda.com/api/url_track_click_mouser/?unipart_id=5659453&manufacturer=Littelfuse Inc.&part_name=PGB1010603MR&search_term=None |  |  | https://www.snapeda.com/parts/PGB1010603MR/Littelfuse/view-part/?ref=snap
EPD_C1 | 1uF/50V | ESP32_WROVER_EAGLE-LTSPICE_CC0402 | ESP32_WROVER_EAGLE-LTSPICE_C0402 | CAPACITOR, European symbol |  |  |  |  |  |  |  |  |  |  |  |  |  |  |  |  |  |  |  |  |  |  |  |  |  |  |  |  |  |  |  |  |  |  | NONE | C
EPD_C2 | 1uF/50V | ESP32_WROVER_EAGLE-LTSPICE_CC0402 | ESP32_WROVER_EAGLE-LTSPICE_C0402 | CAPACITOR, European symbol |  |  |  |  |  |  |  |  |  |  |  |  |  |  |  |  |  |  |  |  |  |  |  |  |  |  |  |  |  |  |  |  |  |  | NONE | C
EPD_C5 | 0.1uF/50V | ESP32_WROVER_EAGLE-LTSPICE_CC0402 | ESP32_WROVER_EAGLE-LTSPICE_C0402 | CAPACITOR, European symbol |  |  |  |  |  |  |  |  |  |  |  |  |  |  |  |  |  |  |  |  |  |  |  |  |  |  |  |  |  |  |  |  |  |  | NONE | C
EPD_C6 | 1uF/50V | ESP32_WROVER_EAGLE-LTSPICE_CC0402 | ESP32_WROVER_EAGLE-LTSPICE_C0402 | CAPACITOR, European symbol |  |  |  |  |  |  |  |  |  |  |  |  |  |  |  |  |  |  |  |  |  |  |  |  |  |  |  |  |  |  |  |  |  |  | NONE | C
EPD_C7 | 1uF/50V | ESP32_WROVER_EAGLE-LTSPICE_CC0402 | ESP32_WROVER_EAGLE-LTSPICE_C0402 | CAPACITOR, European symbol |  |  |  |  |  |  |  |  |  |  |  |  |  |  |  |  |  |  |  |  |  |  |  |  |  |  |  |  |  |  |  |  |  |  | NONE | C
EPD_C8 | 1uF/50V | ESP32_WROVER_EAGLE-LTSPICE_CC0402 | ESP32_WROVER_EAGLE-LTSPICE_C0402 | CAPACITOR, European symbol |  |  |  |  |  |  |  |  |  |  |  |  |  |  |  |  |  |  |  |  |  |  |  |  |  |  |  |  |  |  |  |  |  |  | NONE | C
EPD_C9 | 1uF/50V | ESP32_WROVER_EAGLE-LTSPICE_CC0402 | ESP32_WROVER_EAGLE-LTSPICE_C0402 | CAPACITOR, European symbol |  |  |  |  |  |  |  |  |  |  |  |  |  |  |  |  |  |  |  |  |  |  |  |  |  |  |  |  |  |  |  |  |  |  | NONE | C
EPD_C10 | 1uF/50V | ESP32_WROVER_EAGLE-LTSPICE_CC0402 | ESP32_WROVER_EAGLE-LTSPICE_C0402 | CAPACITOR, European symbol |  |  |  |  |  |  |  |  |  |  |  |  |  |  |  |  |  |  |  |  |  |  |  |  |  |  |  |  |  |  |  |  |  |  | NONE | C
EPD_C11 | 1uF/50V | ESP32_WROVER_EAGLE-LTSPICE_CC0402 | ESP32_WROVER_EAGLE-LTSPICE_C0402 | CAPACITOR, European symbol |  |  |  |  |  |  |  |  |  |  |  |  |  |  |  |  |  |  |  |  |  |  |  |  |  |  |  |  |  |  |  |  |  |  | NONE | C
EPD_C12 | 1uF/50V | ESP32_WROVER_EAGLE-LTSPICE_CC0402 | ESP32_WROVER_EAGLE-LTSPICE_C0402 | CAPACITOR, European symbol |  |  |  |  |  |  |  |  |  |  |  |  |  |  |  |  |  |  |  |  |  |  |  |  |  |  |  |  |  |  |  |  |  |  | NONE | C
IC1 | BD5229G-TR | BD5229G-TR | SOT95P280X125-5N | Voltage Detector with Adjustable Delay Time: CMOS processes are utilized to develop high precision, low current consumption CMOS reset ICs that allow arbitrary setting of the delay time. The extensive lineup includes both Nch Open Drain and CMOS output types in a wide range of detection voltages (from 2.3V to 6.0V, in 0.1V steps), enabling selection of the ideal solution based on customer requirements. In addition, the entire series is of course both lead-free and RoHS-compliant. |  |  |  |  |  |  |  |  |  | Voltage Detector with Adjustable Delay Time: CMOS processes are utilized to develop high precision | low current consumption CMOS reset ICs that allow arbitrary setting of the delay time. The extensive lineup includes both Nch Open Drain and CMOS output types in a wide range of detection voltages (from 2.3V to 6.0V | in 0.1V steps) | enabling selection of the ideal solution based on customer requirements. In addition | the entire series is of course both lead-free and RoHS-compliant. |  |  |  | 1.25mm |  | ROHM Semiconductor | BD5229G-TR |  |  | 755-BD5229G-TR | https://www.mouser.co.uk/ProductDetail/ROHM-Semiconductor/BD5229G-TR?qs=4kLU8WoGk0vvnhrrYwdszw%3D%3D
IC4 | XC6220A331MR-G | XC6220A331MR-G | SOT95P280X120-5N | LDO Voltage Regulators |  |  |  |  |  |  |  |  |  | LDO Voltage Regulators |  |  |  | 1.2mm |  | Torex | XC6220A331MR-G |  |  | 865-XC6220A331MR-G | https://www.mouser.co.uk/ProductDetail/Torex-Semiconductor/XC6220A331MR-G?qs=AsjdqWjXhJ8ZSWznL1J0gg%3D%3D
J1 | FH34SRJ-24S-0.5SH_99_ | FH34SRJ-24S-0.5SH_99_ | FH34SRJ24S05SH99 | (0.50mm) Surface Mount, Right Angle |  |  |  |  |  |  |  |  |  | 24 Position FFC | FPC Connector Contacts | (0.50mm) Surface Mount | Right Angle |  |  |  | 1.1mm |  | Hirose | FH34SRJ-24S-0.5SH(99) |  |  | 798-FH34SRJ24S05SH99 | https://www.mouser.co.uk/ProductDetail/Hirose-Connector/FH34SRJ-24S-0.5SH99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
J2 | SAMACSYS_PARTS_USB4110-GF-A | SAMACSYS_PARTS_USB4110-GF-A | SAMACSYS_PARTS_USB4110GFA | CONN USB 2.0 TYPE-C R/A SMT |  |  |  |  |  |  |  |  |  | CONN USB 2.0 TYPE-C R/A SMT |  |  |  | 3.26mm |  | GCT (GLOBAL CONNECTOR TECHNOLOGY) | USB4110-GF-A |  |  | 640-USB4110-GF-A | https://www.mouser.co.uk/ProductDetail/GCT/USB4110-GF-A?qs=KUoIvG%2F9IlYiZvIXQjyJeA%3D%3D
J3 | QWIIC_RIGHT_ANGLE | QWIIC_CONNECTORJS-1MM | JST04_1MM_RA | SparkFun I2C Standard Qwiic Connector |  |  |  |  |  |  |  |  |  |  |  |  |  |  |  |  |  |  |  |  |  |  |  |  |  |  |  |  |  | CONN-13694 |  |  |  |  |  |  |  |  |  | QWIIC_RIGHT_ANGLE
J4 | 112A-TAAR-R03_ATTEND | 112A-TAAR-R03_ATTEND | 112ATAARR03ATTEND | Micro SD Card Socket, Push-Push Type, Top Mount, SMT, H=1.83mm, 10u |  |  |  |  |  |  |  |  |  | Micro SD Card Socket | Push-Push Type | Top Mount | SMT | H=1.83mm | 10u |  |  |  | 1.9mm |  | ATTEND | 112A-TAAR-R03 ATTEND
L1 | 744043680IND_4828-WE-TPC_WRE | 744043680IND_4828-WE-TPC_WRE | IND_4828-WE-TPC_WRE |  | 68uH |  |  |  |  |  |  | Copyright (C) 2024 Ultra Librarian. All rights reserved. |  |  |  |  |  |  |  |  | 744043680 |  | Wurth Electronics
MCP73831 | ESP32_WROVER_SPARKFUN-IC-POWER_MCP73831 | ESP32_WROVER_SPARKFUN-IC-POWER_MCP73831 | ESP32_WROVER_SPARKFUN-IC-POWER_SOT23-5 | MCP73831T Li-Ion, Li-Pol Controller |  |  |  |  |  |  |  |  |  |  |  |  |  |  |  |  |  |  |  |  |  |  |  |  |  |  |  |  |  | IC-09995
PFMF.050.1 | ESP32C6_VARISTORCN1812 | ESP32C6_VARISTORCN1812 | ESP32C6_VARISTOR_CT/CN1812 | VARISTOR |  |  |  |  |  |  |  |  |  |  |  |  |  |  |  |  |  |  |  |  |  |  |  |  |  |  | 0
Q1 | 20V/4.2A/52mO/1.4W | ESP32_WROVER_SPARKFUN-DISCRETESEMI_MOSFET_PCH-DMG2305UX-7 | ESP32_WROVER_SPARKFUN-DISCRETESEMI_SOT23-3 | P-channel MOSFETs |  |  |  |  |  |  |  |  |  |  |  |  |  |  |  |  |  |  |  |  |  |  |  |  |  |  |  |  |  | TRAN-14388 |  |  |  |  |  |  |  |  |  | 20V/4.2A/52mO/1.4W
Q2 | 20V/4.2A/52mO/1.4W | ESP32_WROVER_SPARKFUN-DISCRETESEMI_MOSFET_PCH-DMG2305UX-7 | ESP32_WROVER_SPARKFUN-DISCRETESEMI_SOT23-3 | P-channel MOSFETs |  |  |  |  |  |  |  |  |  |  |  |  |  |  |  |  |  |  |  |  |  |  |  |  |  |  |  |  |  | TRAN-14388 |  |  |  |  |  |  |  |  |  | 20V/4.2A/52mO/1.4W
Q3 | SI1308EDL-T1-GE3 | SI1308EDL-T1-GE3 | SOT65P210X110-3N | MOSFET N-Ch 30V 1.5A TrenchFET SC70 Vishay Si1308EDL-T1-GE3 N-channel MOSFET Transistor, 1.5 A, 30 V, 3-Pin SC-70 |  |  |  | In Stock |  |  | https://www.snapeda.com/parts/SI1308EDL-T1-GE3/Vishay+Siliconix/view-part/?ref=eda |  |  | Si1308EDL-T1-GE3 N-channel MOSFET Transistor | 1.5 A | 30 V | 3-Pin SC-70 | Siliconix / Vishay SI1308EDL-T1-GE3 |  |  |  |  |  |  |  | Vishay Siliconix |  |  |  |  |  | SI1308EDL-T1-GE3 |  | SOT-323 Vishay Semiconductor |  |  | None |  | https://www.snapeda.com/api/url_track_click_mouser/?unipart_id=274603&manufacturer=Vishay Siliconix&part_name=SI1308EDL-T1-GE3&search_term=None |  |  | https://www.snapeda.com/parts/SI1308EDL-T1-GE3/Vishay+Siliconix/view-part/?ref=snap
R1 | 10K | ESP32_WROVER_EAGLE-LTSPICE_RR0402 | ESP32_WROVER_EAGLE-LTSPICE_R0402 | RESISTOR, European symbol |  |  |  |  |  |  |  |  |  |  |  |  |  |  |  |  |  |  |  |  |  |  |  |  |  |  |  |  |  |  |  |  |  |  | NONE | R
R1_BAT | 200 | ESP32_WROVER_EAGLE-LTSPICE_RR0402 | ESP32_WROVER_EAGLE-LTSPICE_R0402 | RESISTOR, European symbol |  |  |  |  |  |  |  |  |  |  |  |  |  |  |  |  |  |  |  |  |  |  |  |  |  |  |  |  |  |  |  |  |  |  | NONE | R
R1_PINH | 10K | ESP32_WROVER_EAGLE-LTSPICE_RR0402 | ESP32_WROVER_EAGLE-LTSPICE_R0402 | RESISTOR, European symbol |  |  |  |  |  |  |  |  |  |  |  |  |  |  |  |  |  |  |  |  |  |  |  |  |  |  |  |  |  |  |  |  |  |  | NONE | R
R1_PINH1 | 10K | ESP32_WROVER_EAGLE-LTSPICE_RR0402 | ESP32_WROVER_EAGLE-LTSPICE_R0402 | RESISTOR, European symbol |  |  |  |  |  |  |  |  |  |  |  |  |  |  |  |  |  |  |  |  |  |  |  |  |  |  |  |  |  |  |  |  |  |  | NONE | R
R1_PWRUSB | 100K | ESP32_WROVER_EAGLE-LTSPICE_RR0402 | ESP32_WROVER_EAGLE-LTSPICE_R0402 | RESISTOR, European symbol |  |  |  |  |  |  |  |  |  |  |  |  |  |  |  |  |  |  |  |  |  |  |  |  |  |  |  |  |  |  |  |  |  |  | NONE | R
R2 | 2.2 | ESP32_WROVER_EAGLE-LTSPICE_RR0402 | ESP32_WROVER_EAGLE-LTSPICE_R0402 | RESISTOR, European symbol |  |  |  |  |  |  |  |  |  |  |  |  |  |  |  |  |  |  |  |  |  |  |  |  |  |  |  |  |  |  |  |  |  |  | NONE | R
R2-PINH1 | 10K | ESP32_WROVER_EAGLE-LTSPICE_RR0402 | ESP32_WROVER_EAGLE-LTSPICE_R0402 | RESISTOR, European symbol |  |  |  |  |  |  |  |  |  |  |  |  |  |  |  |  |  |  |  |  |  |  |  |  |  |  |  |  |  |  |  |  |  |  | NONE | R
R2-USB | 5k1 | ESP32_WROVER_EAGLE-LTSPICE_RR0402 | ESP32_WROVER_EAGLE-LTSPICE_R0402 | RESISTOR, European symbol |  |  |  |  |  |  |  |  |  |  |  |  |  |  |  |  |  |  |  |  |  |  |  |  |  |  |  |  |  |  |  |  |  |  | NONE | R
R2-USB1 | 5k1 | ESP32_WROVER_EAGLE-LTSPICE_RR0402 | ESP32_WROVER_EAGLE-LTSPICE_R0402 | RESISTOR, European symbol |  |  |  |  |  |  |  |  |  |  |  |  |  |  |  |  |  |  |  |  |  |  |  |  |  |  |  |  |  |  |  |  |  |  | NONE | R
R2_BAT | 2K | ESP32_WROVER_EAGLE-LTSPICE_RR0402 | ESP32_WROVER_EAGLE-LTSPICE_R0402 | RESISTOR, European symbol |  |  |  |  |  |  |  |  |  |  |  |  |  |  |  |  |  |  |  |  |  |  |  |  |  |  |  |  |  |  |  |  |  |  | NONE | R
R2_PINH | 10K | ESP32_WROVER_EAGLE-LTSPICE_RR0402 | ESP32_WROVER_EAGLE-LTSPICE_R0402 | RESISTOR, European symbol |  |  |  |  |  |  |  |  |  |  |  |  |  |  |  |  |  |  |  |  |  |  |  |  |  |  |  |  |  |  |  |  |  |  | NONE | R
R3 | 0.47 | ESP32_WROVER_EAGLE-LTSPICE_RR0402 | ESP32_WROVER_EAGLE-LTSPICE_R0402 | RESISTOR, European symbol |  |  |  |  |  |  |  |  |  |  |  |  |  |  |  |  |  |  |  |  |  |  |  |  |  |  |  |  |  |  |  |  |  |  | NONE | R
R4 | 10K | ESP32_WROVER_EAGLE-LTSPICE_RR0402 | ESP32_WROVER_EAGLE-LTSPICE_R0402 | RESISTOR, European symbol |  |  |  |  |  |  |  |  |  |  |  |  |  |  |  |  |  |  |  |  |  |  |  |  |  |  |  |  |  |  |  |  |  |  | NONE | R
R5 | 10K | ESP32_WROVER_EAGLE-LTSPICE_RR0402 | ESP32_WROVER_EAGLE-LTSPICE_R0402 | RESISTOR, European symbol |  |  |  |  |  |  |  |  |  |  |  |  |  |  |  |  |  |  |  |  |  |  |  |  |  |  |  |  |  |  |  |  |  |  | NONE | R
R6 | 10K | ESP32_WROVER_EAGLE-LTSPICE_RR0402 | ESP32_WROVER_EAGLE-LTSPICE_R0402 | RESISTOR, European symbol |  |  |  |  |  |  |  |  |  |  |  |  |  |  |  |  |  |  |  |  |  |  |  |  |  |  |  |  |  |  |  |  |  |  | NONE | R
R7 | 10K | ESP32_WROVER_EAGLE-LTSPICE_RR0402 | ESP32_WROVER_EAGLE-LTSPICE_R0402 | RESISTOR, European symbol |  |  |  |  |  |  |  |  |  |  |  |  |  |  |  |  |  |  |  |  |  |  |  |  |  |  |  |  |  |  |  |  |  |  | NONE | R
R8 | 10K | ESP32_WROVER_EAGLE-LTSPICE_RR0402 | ESP32_WROVER_EAGLE-LTSPICE_R0402 | RESISTOR, European symbol |  |  |  |  |  |  |  |  |  |  |  |  |  |  |  |  |  |  |  |  |  |  |  |  |  |  |  |  |  |  |  |  |  |  | NONE | R
R9 | 10K | ESP32_WROVER_EAGLE-LTSPICE_RR0402 | ESP32_WROVER_EAGLE-LTSPICE_R0402 | RESISTOR, European symbol |  |  |  |  |  |  |  |  |  |  |  |  |  |  |  |  |  |  |  |  |  |  |  |  |  |  |  |  |  |  |  |  |  |  | NONE | R
R10 | 10K | ESP32_WROVER_EAGLE-LTSPICE_RR0402 | ESP32_WROVER_EAGLE-LTSPICE_R0402 | RESISTOR, European symbol |  |  |  |  |  |  |  |  |  |  |  |  |  |  |  |  |  |  |  |  |  |  |  |  |  |  |  |  |  |  |  |  |  |  | NONE | R
RESET_BUTTON | BUTTON_CUSYOMV1 | BUTTON_CUSYOMV1 | MYBUTTON
R_BOOT | 10k | ESP32_WROVER_EAGLE-LTSPICE_RR0402 | ESP32_WROVER_EAGLE-LTSPICE_R0402 | RESISTOR, European symbol |  |  |  |  |  |  |  |  |  |  |  |  |  |  |  |  |  |  |  |  |  |  |  |  |  |  |  |  |  |  |  |  |  |  | NONE | R
R_CAPACITOR | 15 | ESP32_WROVER_EAGLE-LTSPICE_RR0402 | ESP32_WROVER_EAGLE-LTSPICE_R0402 | RESISTOR, European symbol |  |  |  |  |  |  |  |  |  |  |  |  |  |  |  |  |  |  |  |  |  |  |  |  |  |  |  |  |  |  |  |  |  |  | NONE | R
R_CHANGE | 10k | ESP32_WROVER_EAGLE-LTSPICE_RR0402 | ESP32_WROVER_EAGLE-LTSPICE_R0402 | RESISTOR, European symbol |  |  |  |  |  |  |  |  |  |  |  |  |  |  |  |  |  |  |  |  |  |  |  |  |  |  |  |  |  |  |  |  |  |  | NONE | R
R_CL1 | 10K | ESP32_WROVER_EAGLE-LTSPICE_RR0402 | ESP32_WROVER_EAGLE-LTSPICE_R0402 | RESISTOR, European symbol |  |  |  |  |  |  |  |  |  |  |  |  |  |  |  |  |  |  |  |  |  |  |  |  |  |  |  |  |  |  |  |  |  |  | NONE | R
R_RESET | 10k | ESP32_WROVER_EAGLE-LTSPICE_RR0402 | ESP32_WROVER_EAGLE-LTSPICE_R0402 | RESISTOR, European symbol |  |  |  |  |  |  |  |  |  |  |  |  |  |  |  |  |  |  |  |  |  |  |  |  |  |  |  |  |  |  |  |  |  |  | NONE | R
SENSOR2 | ESP32_WROVER_BME680_BME680 | ESP32_WROVER_BME680_BME680 | ESP32_WROVER_BME680_PSON80P300X300X100-8N | Integrated Environmental Unit |  |  |  | Unavailable |  |  |  |  |  | Integrated Environmental Unit |  |  |  |  |  |  |  | Bosch Sensortec |  |  |  |  |  | BME680 |  | LGA-8 Bosch Tools |  |  | None
SJ1 |  | SJ | SJ | SMD solder JUMPER |  |  |  |  |  |  |  |  |  |  |  |  |  |  |  |  |  |  |  |  |  |  |  |  |  |  | 3
TP1 | TPTP20R | TPTP20R | TP20R | Test pad |  |  |  |  |  |  |  |  |  |  |  |  |  |  |  |  |  |  |  |  |  |  |  |  |  |  | 2
TP2 | TPTP20R | TPTP20R | TP20R | Test pad |  |  |  |  |  |  |  |  |  |  |  |  |  |  |  |  |  |  |  |  |  |  |  |  |  |  | 2
TP3 | TPTP20R | TPTP20R | TP20R | Test pad |  |  |  |  |  |  |  |  |  |  |  |  |  |  |  |  |  |  |  |  |  |  |  |  |  |  | 2
TP4 | TPTP20R | TPTP20R | TP20R | Test pad |  |  |  |  |  |  |  |  |  |  |  |  |  |  |  |  |  |  |  |  |  |  |  |  |  |  | 2
TP5 | TPTP20R | TPTP20R | TP20R | Test pad |  |  |  |  |  |  |  |  |  |  |  |  |  |  |  |  |  |  |  |  |  |  |  |  |  |  | 2
TP6 | TPTP20R | TPTP20R | TP20R | Test pad |  |  |  |  |  |  |  |  |  |  |  |  |  |  |  |  |  |  |  |  |  |  |  |  |  |  | 2
TP7 | TPTP20R | TPTP20R | TP20R | Test pad |  |  |  |  |  |  |  |  |  |  |  |  |  |  |  |  |  |  |  |  |  |  |  |  |  |  | 2
TP8 | TPTP20R | TPTP20R | TP20R | Test pad |  |  |  |  |  |  |  |  |  |  |  |  |  |  |  |  |  |  |  |  |  |  |  |  |  |  | 2
TP9 | TPTP20R | TPTP20R | TP20R | Test pad |  |  |  |  |  |  |  |  |  |  |  |  |  |  |  |  |  |  |  |  |  |  |  |  |  |  | 2
TP10 | TPTP20R | TPTP20R | TP20R | Test pad |  |  |  |  |  |  |  |  |  |  |  |  |  |  |  |  |  |  |  |  |  |  |  |  |  |  | 2
TP11 | TPTP20R | TPTP20R | TP20R | Test pad |  |  |  |  |  |  |  |  |  |  |  |  |  |  |  |  |  |  |  |  |  |  |  |  |  |  | 2
TP12 | TPTP20R | TPTP20R | TP20R | Test pad |  |  |  |  |  |  |  |  |  |  |  |  |  |  |  |  |  |  |  |  |  |  |  |  |  |  | 2
TP13 | TPTP20R | TPTP20R | TP20R | Test pad |  |  |  |  |  |  |  |  |  |  |  |  |  |  |  |  |  |  |  |  |  |  |  |  |  |  | 2
TP14 | TPTP20R | TPTP20R | TP20R | Test pad |  |  |  |  |  |  |  |  |  |  |  |  |  |  |  |  |  |  |  |  |  |  |  |  |  |  | 2
TP15 | TPTP20R | TPTP20R | TP20R | Test pad |  |  |  |  |  |  |  |  |  |  |  |  |  |  |  |  |  |  |  |  |  |  |  |  |  |  | 2
TP16 | TPTP20R | TPTP20R | TP20R | Test pad |  |  |  |  |  |  |  |  |  |  |  |  |  |  |  |  |  |  |  |  |  |  |  |  |  |  | 2
TP17 | TPTP20R | TPTP20R | TP20R | Test pad |  |  |  |  |  |  |  |  |  |  |  |  |  |  |  |  |  |  |  |  |  |  |  |  |  |  | 2
U1 | W25Q512JVEIQ | W25Q512JVEIQ | SON127P600X800X80-9N | Check availability |  |  |  | In Stock |  |  | https://www.snapeda.com/parts/W25Q512JVEIQ/Winbond+Electronics/view-part/?ref=eda |  |  | FLASH - NOR Memory IC 512Mb (64M x 8) SPI - Quad I/O 133 MHz 8-WSON (8x6) |  |  |  |  |  |  |  | Winbond Electronics |  |  |  |  |  | W25Q512JVEIQ |  | Package |  |  | None |  |  |  |  | https://www.snapeda.com/parts/W25Q512JVEIQ/Winbond+Electronics/view-part/?ref=snap
U2 | ESP32-C6-WROOM-1-N8 | ESP32-C6-WROOM-1-N8 | XCVR_ESP32-C6-WROOM-1-N8 | Check availability |  |  |  | In Stock |  |  | https://www.snapeda.com/parts/ESP32-C6-WROOM-1-N8/Espressif+Systems/view-part/?ref=eda |  |  | Multiprotocol Modules ESP32-C6 module | Wi-Fi 6 in 2.4 GHz band | Bluetooth 5 | Zigbee 3.0 and Thread. ESP34-WROOM Compatible - ENGINEERING SAMPLE |  |  |  |  |  |  |  | Espressif Systems |  |  |  |  |  | ESP32-C6-WROOM-1-N8 |  | None |  |  | None |  |  |  |  | https://www.snapeda.com/parts/ESP32-C6-WROOM-1-N8/Espressif+Systems/view-part/?ref=snap
U3 | DS3231SN# | DS3231SN# | SOIC127P1032X265-16N | Real Time Clock Serial 16-Pin SOIC W T/R Check availability |  |  |  | In Stock |  |  | https://www.snapeda.com/parts/DS3231SN%23/Analog+Devices/view-part/?ref=eda |  |  | Extremely Accurate I²C-Integrated RTC/TCXO/Crystal |  |  |  |  |  |  |  | Analog Devices |  |  |  |  |  | DS3231SN# |  | SOIC-16 Maxim |  |  | None |  | https://www.snapeda.com/api/url_track_click_mouser/?unipart_id=99048&manufacturer=Analog Devices&part_name=DS3231SN#&search_term=None |  |  | https://www.snapeda.com/parts/DS3231SN%23/Analog+Devices/view-part/?ref=snap
U4 | MAX17048G+T10 | MAX17048G+T10 | SON50P200X200X80-9N | Check availability |  |  |  | In Stock |  |  | https://www.snapeda.com/parts/MAX17048G+T10/Analog+Devices/view-part/?ref=eda |  |  | 3µA 1-Cell/2-Cell Fuel Gauge with ModelGauge |  |  |  |  |  |  |  | Analog Devices |  |  |  |  |  | MAX17048G+T10 |  | TDFN-8 Maxim |  |  | None |  | https://www.snapeda.com/api/url_track_click_mouser/?unipart_id=329239&manufacturer=Analog Devices&part_name=MAX17048G+T10&search_term=None |  |  | https://www.snapeda.com/parts/MAX17048G+T10/Analog+Devices/view-part/?ref=snap

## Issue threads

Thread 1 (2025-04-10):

Fix copper width errors

EugenM03, 2025-04-10:
Pentru _Board.prd_ , la rularea DRC, apar erori legate de latimea traseurilor ce pleaca din componente SMD pe stratul top. Trebuie respectata valoarea minima pentru **1 netclass**. Vezi restrictiile si daca regulile sunt importate corect.

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

Closed 2025-04-11.

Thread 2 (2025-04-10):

"Access not allowed" - missing 3D pieces

EugenM03, 2025-04-10:
La vizualizarea PCB-ului in 3D, apare un warning ce enumera componente ce nu pot fi accesate din biblioteca datorita permisiunilor (LED-uri, condensatoare, modulul ESP32_WROVER_EAGLE):

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

Rezultatul este vizibil si pe placuta; de exemplu la condensatori, acestia apar dar nu au forma lor definita, ci una implicita. O reimportare corecta a bibliotecii folosite ar rezolva vizualizarea componentelor.

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

Closed 2025-04-13.

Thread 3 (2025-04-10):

Fix layout issues in schematic design

EugenM03, 2025-04-10:
In schematic, in unele cazuri sunt suprascrise numele ori etichetele.

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

Closed 2025-04-11.

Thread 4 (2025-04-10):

Layout issues in PCB

EugenM03, 2025-04-10:
In PCB, uneori apare text suprascris pe componente, etichete, valori etc. din cauza pozitiei sau dimensiunii.

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

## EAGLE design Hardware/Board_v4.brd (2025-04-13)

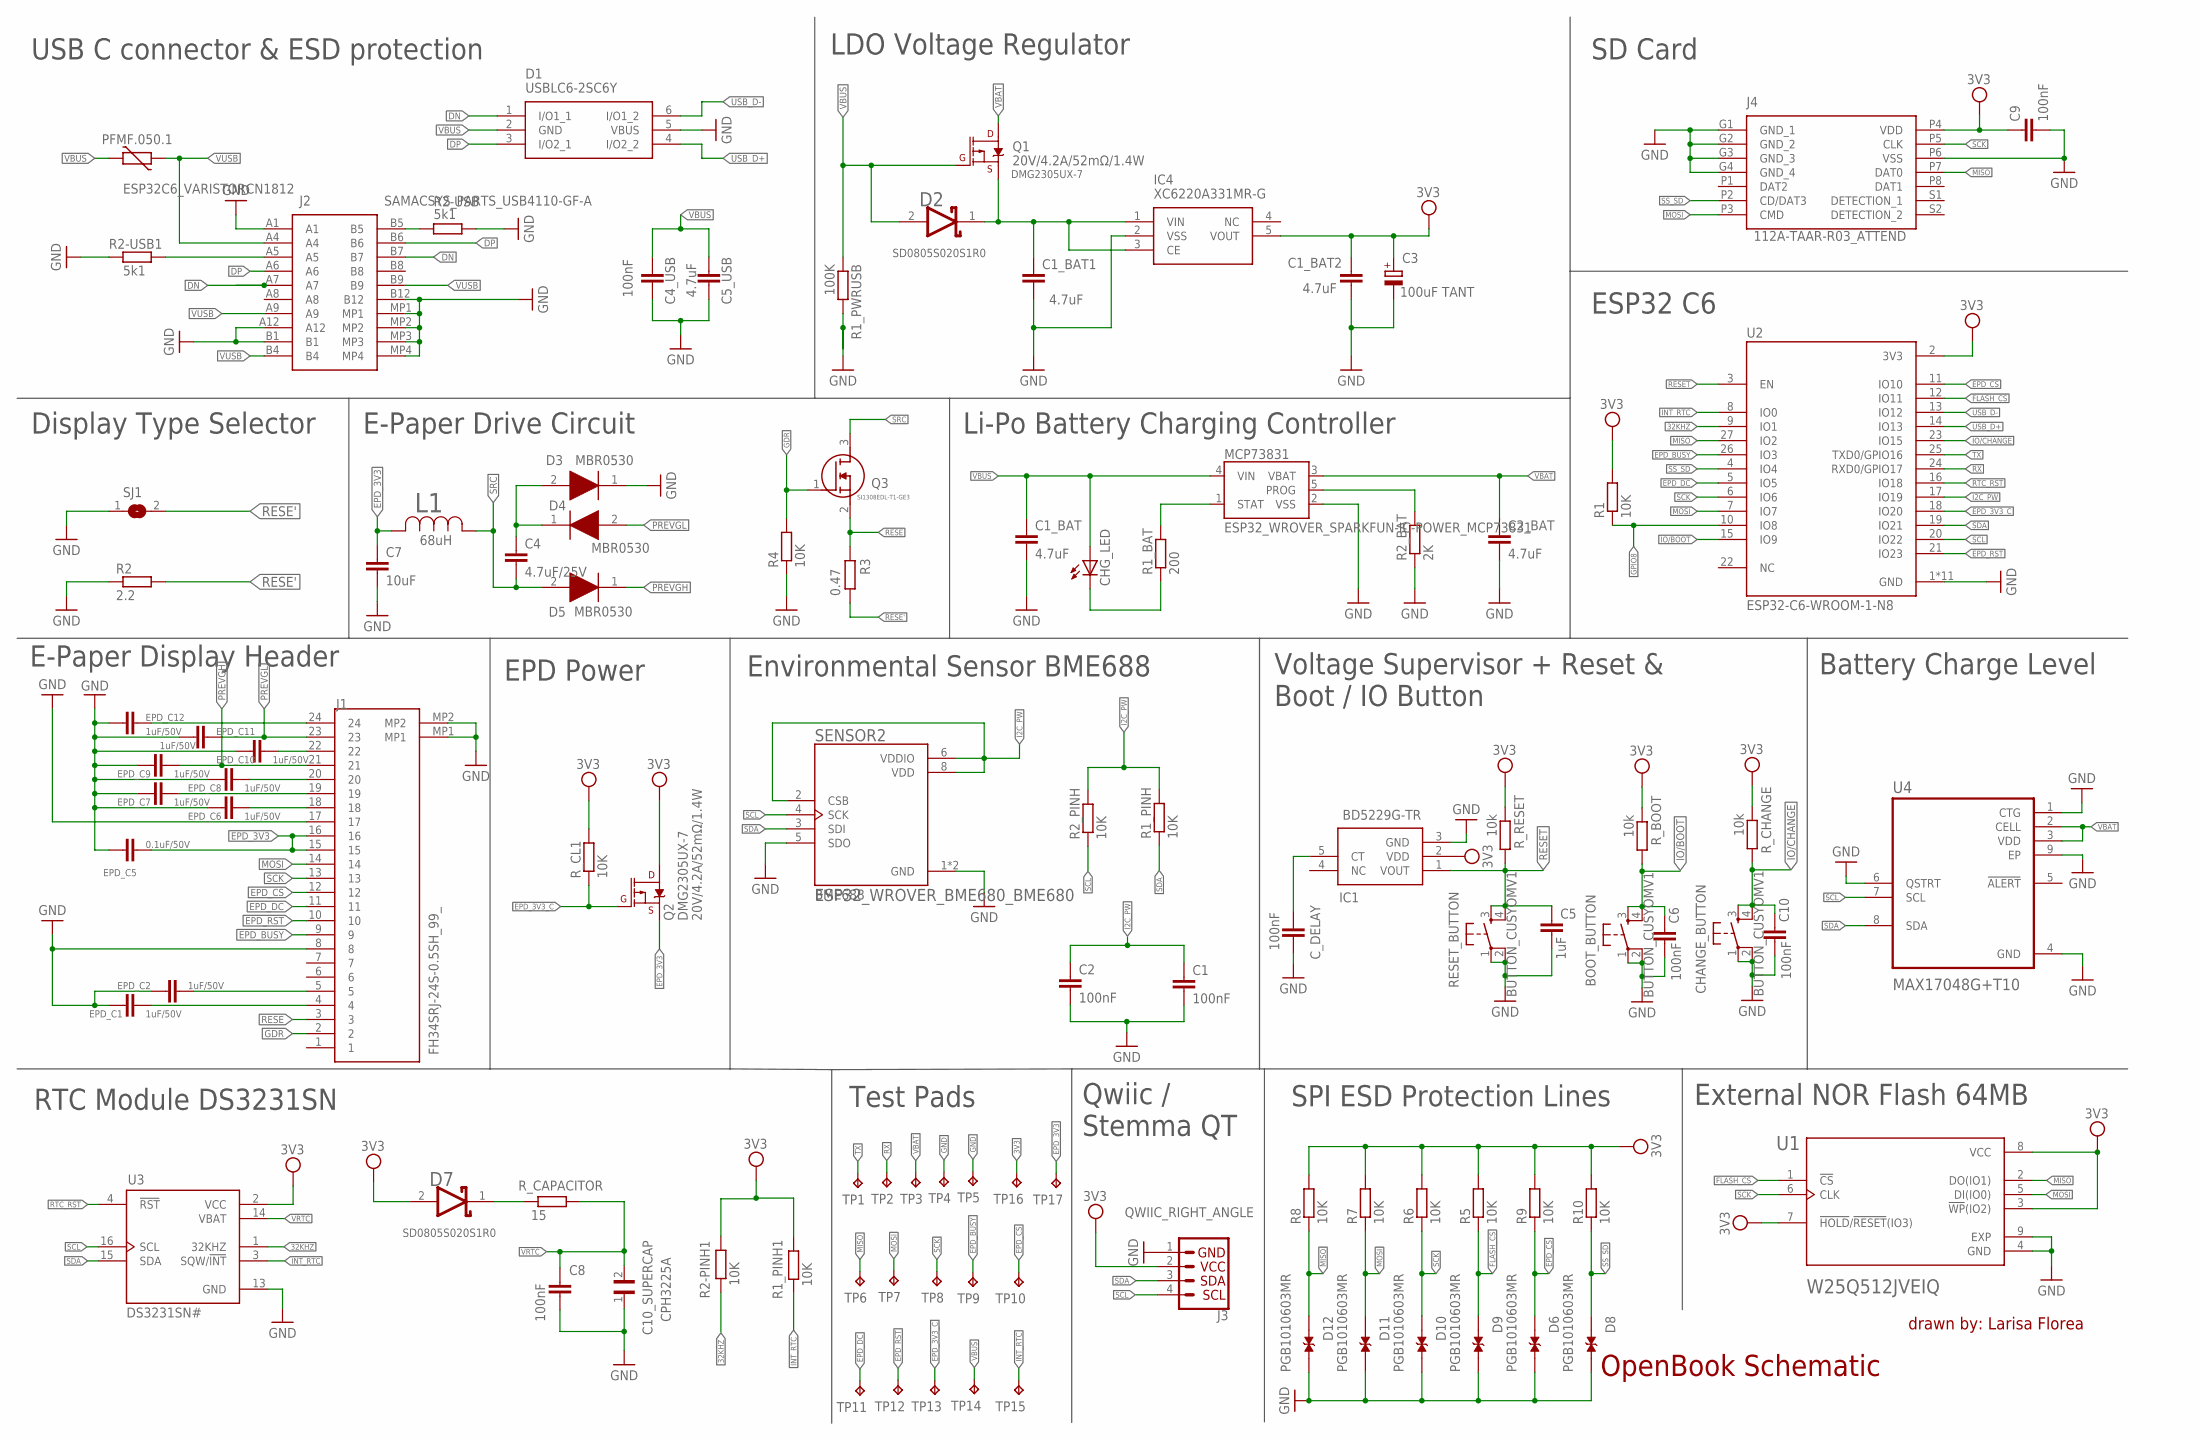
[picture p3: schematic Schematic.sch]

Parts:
BOOT_BUTTON: BUTTON_CUSYOMV1; MYBUTTON
C1, C2, C6, C8, C9, C10: 100nF; EAGLE-LTSPICE_C0402
C1_BAT, C2_BAT: 4.7uF; EAGLE-LTSPICE_C0402
C1_BAT1, C1_BAT2, C5_USB: 4.7uF; ESP32_WROVER_EAGLE-LTSPICE_C0402
C3: 100uF TANT; RCL_CT3528
C4: 4.7uF/25V; ESP32_WROVER_EAGLE-LTSPICE_C0402
C4_USB: 100nF; ESP32_WROVER_EAGLE-LTSPICE_C0402
C5: 1uF; EAGLE-LTSPICE_C0402
C7: 10uF; ESP32_WROVER_EAGLE-LTSPICE_C0402
C10_SUPERCAP: CPH3225A; CAPCP3225X100N
CHANGE_BUTTON: BUTTON_CUSYOMV1; MYBUTTON
CHG_LED: ADAFRUIT_LEDCHIP-LED0603; ADAFRUIT_CHIP-LED0603
C_DELAY: 100nF; EAGLE-LTSPICE_C0402
D1: USBLC6-2SC6Y; SOT95P280X145-6N
D2, D7: ESP32_WROVER_AVX---SD0805S020S1R0_AVX_SD0805S020S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; ESP32_WROVER_AVX---SD0805S020S1R0_AVX_SD0805S020S1R0_0
D3, D4, D5: MBR0530; SOD3716X135N
D6, D8, D9, D10, D11, D12: PGB1010603MR; DIOC1608X36N
EPD_C1, EPD_C2, EPD_C6, EPD_C7, EPD_C8, EPD_C9, EPD_C10, EPD_C11, EPD_C12: 1uF/50V; ESP32_WROVER_EAGLE-LTSPICE_C0402
EPD_C5: 0.1uF/50V; ESP32_WROVER_EAGLE-LTSPICE_C0402
IC1: BD5229G-TR; SOT95P280X125-5N
IC4: XC6220A331MR-G; SOT95P280X120-5N
J1: FH34SRJ-24S-0.5SH_99_; FH34SRJ24S05SH99
J2: SAMACSYS_PARTS_USB4110-GF-A; SAMACSYS_PARTS_USB4110GFA
J3: QWIIC_RIGHT_ANGLE; JST04_1MM_RA
J4: 112A-TAAR-R03_ATTEND; 112ATAARR03ATTEND
L1: 744043680IND_4828-WE-TPC_WRE; IND_4828-WE-TPC_WRE
MCP73831: ESP32_WROVER_SPARKFUN-IC-POWER_MCP73831; ESP32_WROVER_SPARKFUN-IC-POWER_SOT23-5
PFMF.050.1: ESP32C6_VARISTORCN1812; ESP32C6_VARISTOR_CT/CN1812
Q1, Q2: 20V/4.2A/52mΩ/1.4W; ESP32_WROVER_SPARKFUN-DISCRETESEMI_SOT23-3
Q3: SI1308EDL-T1-GE3; SOT65P210X110-3N
R1, R1_PINH, R1_PINH1, R2-PINH1, R2_PINH, R4, R5, R6, R7, R8, R9, R10: 10K; ESP32_WROVER_EAGLE-LTSPICE_R0402
R1_BAT: 200; ESP32_WROVER_EAGLE-LTSPICE_R0402
R1_PWRUSB: 100K; ESP32_WROVER_EAGLE-LTSPICE_R0402
R2: 2.2; ESP32_WROVER_EAGLE-LTSPICE_R0402
R2-USB, R2-USB1: 5k1; ESP32_WROVER_EAGLE-LTSPICE_R0402
R2_BAT: 2K; ESP32_WROVER_EAGLE-LTSPICE_R0402
R3: 0.47; ESP32_WROVER_EAGLE-LTSPICE_R0402
RESET_BUTTON: BUTTON_CUSYOMV1; MYBUTTON
R_BOOT: 10k; ESP32_WROVER_EAGLE-LTSPICE_R0402
R_CAPACITOR: 15; ESP32_WROVER_EAGLE-LTSPICE_R0402
R_CHANGE: 10k; ESP32_WROVER_EAGLE-LTSPICE_R0402
R_CL1: 10K; ESP32_WROVER_EAGLE-LTSPICE_R0402
R_RESET: 10k; ESP32_WROVER_EAGLE-LTSPICE_R0402
SENSOR2: ESP32_WROVER_BME680_BME680; ESP32_WROVER_BME680_PSON80P300X300X100-8N
SJ1: SJ
TP1, TP2, TP3, TP4, TP5, TP6, TP7, TP8, TP9, TP10, TP11, TP12, TP13, TP14, TP15, TP16, TP17: TPTP20R; TP20R
U1: W25Q512JVEIQ; SON127P600X800X80-9N
U2: ESP32-C6-WROOM-1-N8; XCVR_ESP32-C6-WROOM-1-N8
U3: DS3231SN#; SOIC127P1032X265-16N
U4: MAX17048G+T10; SON50P200X200X80-9N

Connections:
3V3: C1_BAT2.1, C3.+, C9.1, D7.2 (ANODE), IC1.2 (VDD), IC4.5 (VOUT), J3.2, J4.P4 (VDD), Q2.3 (D), R1.2, R1_PINH1.2, R2-PINH1.2, R5.2, R6.2, R7.2, R8.2, R9.2, R10.2, R_BOOT.1, R_CHANGE.1, R_CL1.2, R_RESET.1, TP16.TP, U1.3 (!WP!(IO2)), U1.7 (!HOLD!/!RESET!(IO3)), U1.8 (VCC), U2.2 (3V3), U3.2 (VCC)
32KHZ: R2-PINH1.1, U2.9 (IO1), U3.1 (32KHZ)
DN: D1.1 (I/O1_1), J2.A7, J2.B7
DP: D1.3 (I/O2_1), J2.A6, J2.B6
EPD_3V3: C7.1, EPD_C5.1, J1.15, J1.16, L1.2, Q2.2 (S), TP17.TP
EPD_3V3_C: Q2.1 (G), R_CL1.1, TP13.TP, U2.18 (IO20)
EPD_BUSY: J1.9, TP9.TP, U2.26 (IO3)
EPD_CS: D6.1, J1.12, R9.1, TP10.TP, U2.11 (IO10)
EPD_DC: J1.11, TP11.TP, U2.5 (IO5)
EPD_RST: J1.10, TP12.TP, U2.21 (IO23)
FLASH_CS: D9.1, R5.1, U1.1 (!CS), U2.12 (IO11)
GDR: J1.2, Q3.1 (G), R4.2
GND: BOOT_BUTTON.1, BOOT_BUTTON.2, C1.2, C1_BAT.2, C1_BAT1.2, C1_BAT2.2, C2.2, C2_BAT.2, C3.-, C4_USB.2, C5.2, C5_USB.2, C6.2, C7.2, C8.2, C9.2, C10.2, C10_SUPERCAP.1, CHANGE_BUTTON.1, CHANGE_BUTTON.2, C_DELAY.2, D1.5 (VBUS), D3.1 (K), D6.2, D8.2, D9.2, D10.2, D11.2, D12.2, EPD_C1.2, EPD_C2.2, EPD_C5.2, EPD_C6.2, EPD_C7.2, EPD_C8.2, EPD_C9.2, EPD_C10.2, EPD_C11.2, EPD_C12.2, IC1.3 (GND), IC4.2 (VSS), J1.8, J1.17, J1.MP1, J1.MP2, J2.A1, J2.A12, J2.B1, J2.B12, J2.MP1, J2.MP2, J2.MP3, J2.MP4, J3.1, J4.G1 (GND_1), J4.G2 (GND_2), J4.G3 (GND_3), J4.G4 (GND_4), J4.P6 (VSS), MCP73831.2 (VSS), R1_PWRUSB.2, R2.1, R2-USB.2, R2-USB1.1, R2_BAT.1, R4.1, RESET_BUTTON.1, RESET_BUTTON.2, SENSOR2.1 (GND), SENSOR2.5 (SDO), SENSOR2.7 (GND), SJ1.1, TP4.TP, TP5.TP, U1.4 (GND), U1.9 (EXP), U2.1 (GND), U2.28 (GND), U2.29_1 (GND), U2.29_2 (GND), U2.29_3 (GND), U2.29_4 (GND), U2.29_5 (GND), U2.29_6 (GND), U2.29_7 (GND), U2.29_8 (GND), U2.29_9 (GND), U3.13 (GND), U4.1 (CTG), U4.4 (GND), U4.6 (QSTRT), U4.9 (EP)
GPIO8: R1.1, U2.10 (IO8)
I2C_PW: C1.1, C2.1, R1_PINH.2, R2_PINH.2, SENSOR2.2 (CSB), SENSOR2.6 (VDDIO), SENSOR2.8 (VDD), U2.17 (IO19)
INT_RTC: R1_PINH1.1, TP15.TP, U2.8 (IO0), U3.3 (SQW/!INT)
IO/BOOT: BOOT_BUTTON.3, BOOT_BUTTON.4, C6.1, R_BOOT.2, U2.15 (IO9)
IO/CHANGE: C10.1, CHANGE_BUTTON.3, CHANGE_BUTTON.4, R_CHANGE.2, U2.23 (IO15)
MISO: D12.1, J4.P7 (DAT0), R8.1, TP6.TP, U1.2 (DO(IO1)), U2.27 (IO2)
MOSI: D11.1, J1.14, J4.P3 (CMD), R7.1, TP7.TP, U1.5 (DI(IO0)), U2.7 (IO7)
unnamed: J2.A5, R2-USB1.2
unnamed: J2.B5, R2-USB.1
unnamed: C1_BAT1.1, D2.1 (CATHODE), IC4.1 (VIN), IC4.3 (CE), Q1.2 (S)
unnamed: CHG_LED.C, R1_BAT.1
unnamed: MCP73831.1 (STAT), R1_BAT.2
unnamed: C4.1, D3.2 (A), D4.1 (K)
unnamed: MCP73831.5 (PROG), R2_BAT.2
unnamed: C_DELAY.1, IC1.5 (CT)
unnamed: D7.1 (CATHODE), R_CAPACITOR.1
unnamed: EPD_C12.1, J1.24
unnamed: EPD_C6.1, J1.18
unnamed: EPD_C7.1, J1.19
unnamed: EPD_C8.1, J1.20
unnamed: EPD_C10.1, J1.22
unnamed: EPD_C2.1, J1.5
unnamed: EPD_C1.1, J1.4
PREVGH: D5.1 (K), EPD_C9.1, J1.21
PREVGL: D4.2 (A), EPD_C11.1, J1.23
RESE: J1.3, Q3.2 (S), R3.2
RESE': R2.2, R3.1, SJ1.2
RESET: C5.1, IC1.1 (VOUT), RESET_BUTTON.3, RESET_BUTTON.4, R_RESET.2, U2.3 (EN)
RTC_RST: U2.16 (IO18), U3.4 (!RST)
RX: TP2.TP, U2.24 (RXD0/GPIO17)
SCK: D10.1, J1.13, J4.P5 (CLK), R6.1, TP8.TP, U1.6 (CLK), U2.6 (IO6)
SCL: J3.4, R2_PINH.1, SENSOR2.4 (SCK), U2.20 (IO22), U3.16 (SCL), U4.7 (SCL)
SDA: J3.3, R1_PINH.1, SENSOR2.3 (SDI), U2.19 (IO21), U3.15 (SDA), U4.8 (SDA)
SRC: C4.2, D5.2 (A), L1.1, Q3.3 (D)
SS_SD: D8.1, J4.P2 (CD/DAT3), R10.1, U2.4 (IO4)
TX: TP1.TP, U2.25 (TXD0/GPIO16)
USB_D+: D1.4 (I/O2_2), U2.14 (IO13)
USB_D-: D1.6 (I/O1_2), U2.13 (IO12)
VBAT: C2_BAT.1, MCP73831.3 (VBAT), Q1.3 (D), TP3.TP, U4.2 (CELL), U4.3 (VDD)
VBUS: C1_BAT.1, C4_USB.1, C5_USB.1, CHG_LED.A, D1.2 (GND), D2.2 (ANODE), MCP73831.4 (VIN), PFMF.050.1.2, Q1.1 (G), R1_PWRUSB.1, TP14.TP
VRTC: C8.1, C10_SUPERCAP.2, R_CAPACITOR.2, U3.14 (VBAT)
VUSB: J2.A4, J2.A9, J2.B4, J2.B9, PFMF.050.1.1

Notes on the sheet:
USB C connector & ESD protection
Display Type Selector
E-Paper Drive Circuit
Li-Po Battery Charging Controller
SD Card
ESP32 C6
EPD Power
Environmental Sensor BME688
Voltage Supervisor + Reset & Boot / IO Button
LDO Voltage Regulator
Battery Charge Level
RTC Module DS3231SN
Test Pads
Qwiic / Stemma QT
SPI ESD Protection Lines
External NOR Flash 64MB
OpenBook Schematic
drawn by: Larisa Florea
E-Paper Display Header

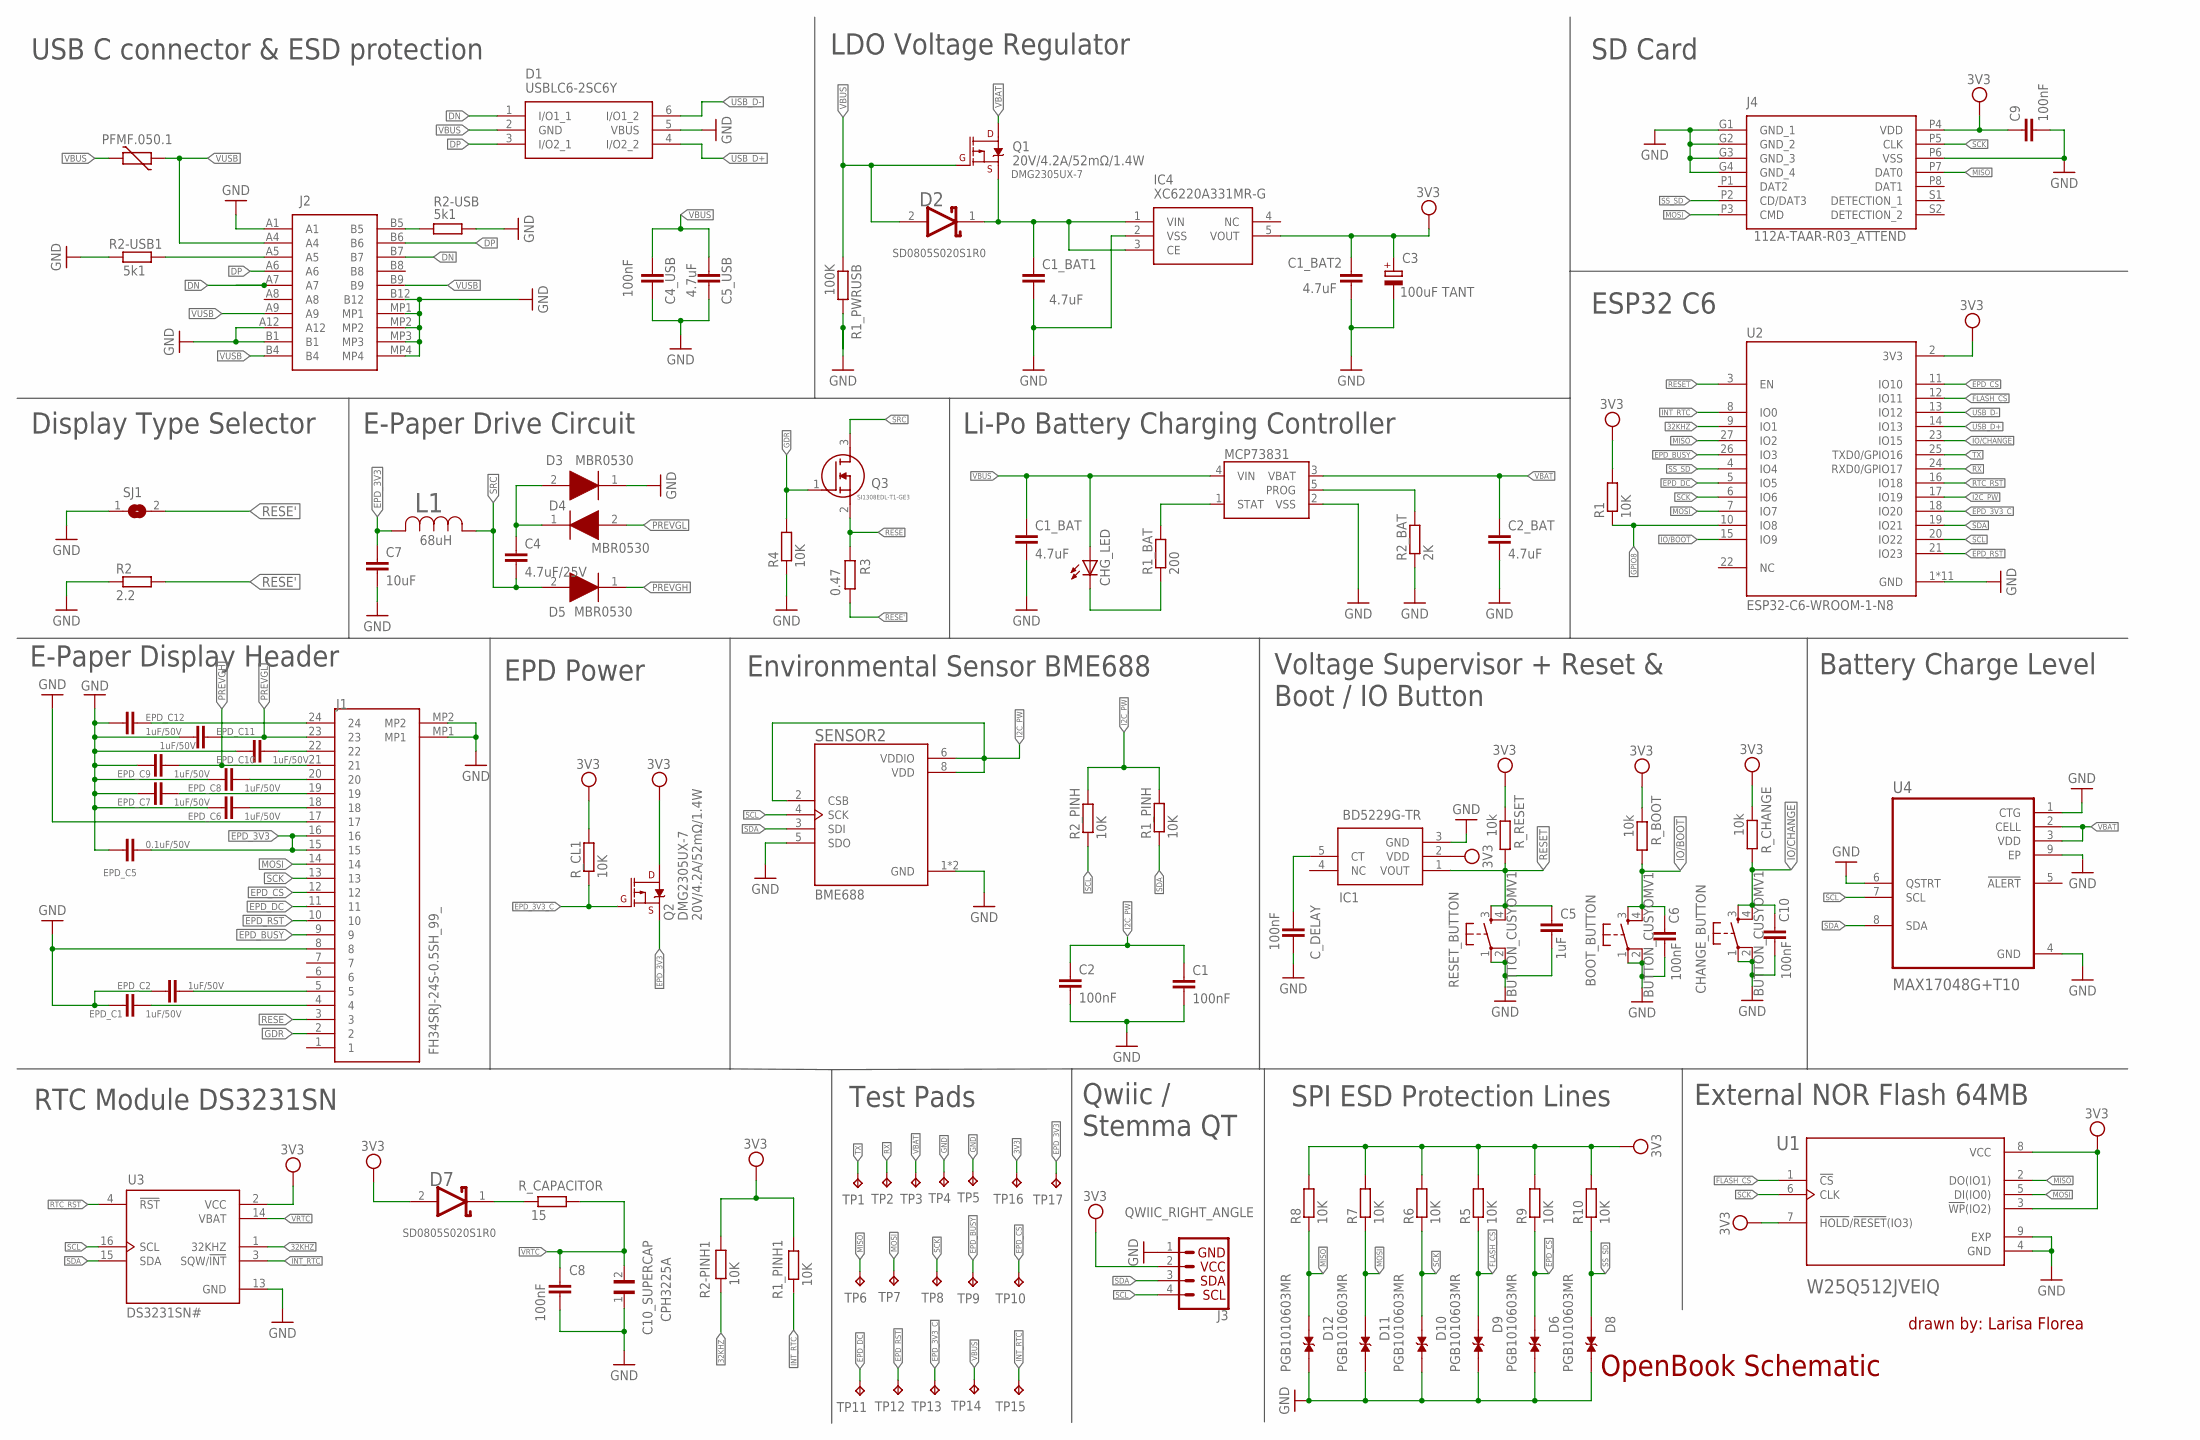
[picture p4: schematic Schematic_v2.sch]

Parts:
BOOT_BUTTON: BUTTON_CUSYOMV1; MYBUTTON
C1, C2, C6, C8, C9, C10: 100nF; EAGLE-LTSPICE_C0402
C1_BAT, C2_BAT: 4.7uF; EAGLE-LTSPICE_C0402
C1_BAT1, C1_BAT2, C5_USB: 4.7uF; ESP32_WROVER_EAGLE-LTSPICE_C0402
C3: 100uF TANT; RCL_CT3528
C4: 4.7uF/25V; ESP32_WROVER_EAGLE-LTSPICE_C0402
C4_USB: 100nF; ESP32_WROVER_EAGLE-LTSPICE_C0402
C5: 1uF; EAGLE-LTSPICE_C0402
C7: 10uF; ESP32_WROVER_EAGLE-LTSPICE_C0402
C10_SUPERCAP: CPH3225A; CAPCP3225X100N
CHANGE_BUTTON: BUTTON_CUSYOMV1; MYBUTTON
CHG_LED: ADAFRUIT_LEDCHIP-LED0603; ADAFRUIT_CHIP-LED0603
C_DELAY: 100nF; EAGLE-LTSPICE_C0402
D1: USBLC6-2SC6Y; SOT95P280X145-6N
D2, D7: ESP32_WROVER_AVX---SD0805S020S1R0_AVX_SD0805S020S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; ESP32_WROVER_AVX---SD0805S020S1R0_AVX_SD0805S020S1R0_0
D3, D4, D5: MBR0530; SOD3716X135N
D6, D8, D9, D10, D11, D12: PGB1010603MR; DIOC1608X36N
EPD_C1, EPD_C2, EPD_C6, EPD_C7, EPD_C8, EPD_C9, EPD_C10, EPD_C11, EPD_C12: 1uF/50V; ESP32_WROVER_EAGLE-LTSPICE_C0402
EPD_C5: 0.1uF/50V; ESP32_WROVER_EAGLE-LTSPICE_C0402
IC1: BD5229G-TR; SOT95P280X125-5N
IC4: XC6220A331MR-G; SOT95P280X120-5N
J1: FH34SRJ-24S-0.5SH_99_; FH34SRJ24S05SH99
J2: SAMACSYS_PARTS_USB4110-GF-A; SAMACSYS_PARTS_USB4110GFA
J3: QWIIC_RIGHT_ANGLE; JST04_1MM_RA
J4: 112A-TAAR-R03_ATTEND; 112ATAARR03ATTEND
L1: 744043680IND_4828-WE-TPC_WRE; IND_4828-WE-TPC_WRE
MCP73831: ESP32_WROVER_SPARKFUN-IC-POWER_MCP73831; ESP32_WROVER_SPARKFUN-IC-POWER_SOT23-5
PFMF.050.1: ESP32C6_VARISTORCN1812; ESP32C6_VARISTOR_CT/CN1812
Q1, Q2: 20V/4.2A/52mΩ/1.4W; ESP32_WROVER_SPARKFUN-DISCRETESEMI_SOT23-3
Q3: SI1308EDL-T1-GE3; SOT65P210X110-3N
R1, R1_PINH, R1_PINH1, R2-PINH1, R2_PINH, R4, R5, R6, R7, R8, R9, R10: 10K; ESP32_WROVER_EAGLE-LTSPICE_R0402
R1_BAT: 200; ESP32_WROVER_EAGLE-LTSPICE_R0402
R1_PWRUSB: 100K; ESP32_WROVER_EAGLE-LTSPICE_R0402
R2: 2.2; ESP32_WROVER_EAGLE-LTSPICE_R0402
R2-USB, R2-USB1: 5k1; ESP32_WROVER_EAGLE-LTSPICE_R0402
R2_BAT: 2K; ESP32_WROVER_EAGLE-LTSPICE_R0402
R3: 0.47; ESP32_WROVER_EAGLE-LTSPICE_R0402
RESET_BUTTON: BUTTON_CUSYOMV1; MYBUTTON
R_BOOT: 10k; ESP32_WROVER_EAGLE-LTSPICE_R0402
R_CAPACITOR: 15; ESP32_WROVER_EAGLE-LTSPICE_R0402
R_CHANGE: 10k; ESP32_WROVER_EAGLE-LTSPICE_R0402
R_CL1: 10K; ESP32_WROVER_EAGLE-LTSPICE_R0402
R_RESET: 10k; ESP32_WROVER_EAGLE-LTSPICE_R0402
SENSOR2: ESP32_WROVER_BME680_BME680; ESP32_WROVER_BME680_PSON80P300X300X100-8N
SJ1: SJ
TP1, TP2, TP3, TP4, TP5, TP6, TP7, TP8, TP9, TP10, TP11, TP12, TP13, TP14, TP15, TP16, TP17: TPTP20R; TP20R
U1: W25Q512JVEIQ; SON127P600X800X80-9N
U2: ESP32-C6-WROOM-1-N8; XCVR_ESP32-C6-WROOM-1-N8
U3: DS3231SN#; SOIC127P1032X265-16N
U4: MAX17048G+T10; SON50P200X200X80-9N

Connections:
3V3: C1_BAT2.1, C3.+, C9.1, D7.2 (ANODE), IC1.2 (VDD), IC4.5 (VOUT), J3.2, J4.P4 (VDD), Q2.3 (D), R1.2, R1_PINH1.2, R2-PINH1.2, R5.2, R6.2, R7.2, R8.2, R9.2, R10.2, R_BOOT.1, R_CHANGE.1, R_CL1.2, R_RESET.1, TP16.TP, U1.3 (!WP!(IO2)), U1.7 (!HOLD!/!RESET!(IO3)), U1.8 (VCC), U2.2 (3V3), U3.2 (VCC)
32KHZ: R2-PINH1.1, U2.9 (IO1), U3.1 (32KHZ)
DN: D1.1 (I/O1_1), J2.A7, J2.B7
DP: D1.3 (I/O2_1), J2.A6, J2.B6
EPD_3V3: C7.1, EPD_C5.1, J1.15, J1.16, L1.2, Q2.2 (S), TP17.TP
EPD_3V3_C: Q2.1 (G), R_CL1.1, TP13.TP, U2.18 (IO20)
EPD_BUSY: J1.9, TP9.TP, U2.26 (IO3)
EPD_CS: D6.1, J1.12, R9.1, TP10.TP, U2.11 (IO10)
EPD_DC: J1.11, TP11.TP, U2.5 (IO5)
EPD_RST: J1.10, TP12.TP, U2.21 (IO23)
FLASH_CS: D9.1, R5.1, U1.1 (!CS), U2.12 (IO11)
GDR: J1.2, Q3.1 (G), R4.2
GND: BOOT_BUTTON.1, BOOT_BUTTON.2, C1.2, C1_BAT.2, C1_BAT1.2, C1_BAT2.2, C2.2, C2_BAT.2, C3.-, C4_USB.2, C5.2, C5_USB.2, C6.2, C7.2, C8.2, C9.2, C10.2, C10_SUPERCAP.1, CHANGE_BUTTON.1, CHANGE_BUTTON.2, C_DELAY.2, D1.5 (VBUS), D3.1 (K), D6.2, D8.2, D9.2, D10.2, D11.2, D12.2, EPD_C1.2, EPD_C2.2, EPD_C5.2, EPD_C6.2, EPD_C7.2, EPD_C8.2, EPD_C9.2, EPD_C10.2, EPD_C11.2, EPD_C12.2, IC1.3 (GND), IC4.2 (VSS), J1.8, J1.17, J1.MP1, J1.MP2, J2.A1, J2.A12, J2.B1, J2.B12, J2.MP1, J2.MP2, J2.MP3, J2.MP4, J3.1, J4.G1 (GND_1), J4.G2 (GND_2), J4.G3 (GND_3), J4.G4 (GND_4), J4.P6 (VSS), MCP73831.2 (VSS), R1_PWRUSB.2, R2.1, R2-USB.2, R2-USB1.1, R2_BAT.1, R4.1, RESET_BUTTON.1, RESET_BUTTON.2, SENSOR2.1 (GND), SENSOR2.5 (SDO), SENSOR2.7 (GND), SJ1.1, TP4.TP, TP5.TP, U1.4 (GND), U1.9 (EXP), U2.1 (GND), U2.28 (GND), U2.29_1 (GND), U2.29_2 (GND), U2.29_3 (GND), U2.29_4 (GND), U2.29_5 (GND), U2.29_6 (GND), U2.29_7 (GND), U2.29_8 (GND), U2.29_9 (GND), U3.13 (GND), U4.1 (CTG), U4.4 (GND), U4.6 (QSTRT), U4.9 (EP)
GPIO8: R1.1, U2.10 (IO8)
I2C_PW: C1.1, C2.1, R1_PINH.2, R2_PINH.2, SENSOR2.2 (CSB), SENSOR2.6 (VDDIO), SENSOR2.8 (VDD), U2.17 (IO19)
INT_RTC: R1_PINH1.1, TP15.TP, U2.8 (IO0), U3.3 (SQW/!INT)
IO/BOOT: BOOT_BUTTON.3, BOOT_BUTTON.4, C6.1, R_BOOT.2, U2.15 (IO9)
IO/CHANGE: C10.1, CHANGE_BUTTON.3, CHANGE_BUTTON.4, R_CHANGE.2, U2.23 (IO15)
MISO: D12.1, J4.P7 (DAT0), R8.1, TP6.TP, U1.2 (DO(IO1)), U2.27 (IO2)
MOSI: D11.1, J1.14, J4.P3 (CMD), R7.1, TP7.TP, U1.5 (DI(IO0)), U2.7 (IO7)
unnamed: J2.A5, R2-USB1.2
unnamed: J2.B5, R2-USB.1
unnamed: C1_BAT1.1, D2.1 (CATHODE), IC4.1 (VIN), IC4.3 (CE), Q1.2 (S)
unnamed: CHG_LED.C, R1_BAT.1
unnamed: MCP73831.1 (STAT), R1_BAT.2
unnamed: C4.1, D3.2 (A), D4.1 (K)
unnamed: MCP73831.5 (PROG), R2_BAT.2
unnamed: C_DELAY.1, IC1.5 (CT)
unnamed: D7.1 (CATHODE), R_CAPACITOR.1
unnamed: EPD_C12.1, J1.24
unnamed: EPD_C6.1, J1.18
unnamed: EPD_C7.1, J1.19
unnamed: EPD_C8.1, J1.20
unnamed: EPD_C10.1, J1.22
unnamed: EPD_C2.1, J1.5
unnamed: EPD_C1.1, J1.4
PREVGH: D5.1 (K), EPD_C9.1, J1.21
PREVGL: D4.2 (A), EPD_C11.1, J1.23
RESE: J1.3, Q3.2 (S), R3.2
RESE': R2.2, R3.1, SJ1.2
RESET: C5.1, IC1.1 (VOUT), RESET_BUTTON.3, RESET_BUTTON.4, R_RESET.2, U2.3 (EN)
RTC_RST: U2.16 (IO18), U3.4 (!RST)
RX: TP2.TP, U2.24 (RXD0/GPIO17)
SCK: D10.1, J1.13, J4.P5 (CLK), R6.1, TP8.TP, U1.6 (CLK), U2.6 (IO6)
SCL: J3.4, R2_PINH.1, SENSOR2.4 (SCK), U2.20 (IO22), U3.16 (SCL), U4.7 (SCL)
SDA: J3.3, R1_PINH.1, SENSOR2.3 (SDI), U2.19 (IO21), U3.15 (SDA), U4.8 (SDA)
SRC: C4.2, D5.2 (A), L1.1, Q3.3 (D)
SS_SD: D8.1, J4.P2 (CD/DAT3), R10.1, U2.4 (IO4)
TX: TP1.TP, U2.25 (TXD0/GPIO16)
USB_D+: D1.4 (I/O2_2), U2.14 (IO13)
USB_D-: D1.6 (I/O1_2), U2.13 (IO12)
VBAT: C2_BAT.1, MCP73831.3 (VBAT), Q1.3 (D), TP3.TP, U4.2 (CELL), U4.3 (VDD)
VBUS: C1_BAT.1, C4_USB.1, C5_USB.1, CHG_LED.A, D1.2 (GND), D2.2 (ANODE), MCP73831.4 (VIN), PFMF.050.1.2, Q1.1 (G), R1_PWRUSB.1, TP14.TP
VRTC: C8.1, C10_SUPERCAP.2, R_CAPACITOR.2, U3.14 (VBAT)
VUSB: J2.A4, J2.A9, J2.B4, J2.B9, PFMF.050.1.1

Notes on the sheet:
USB C connector & ESD protection
Display Type Selector
E-Paper Drive Circuit
Li-Po Battery Charging Controller
SD Card
ESP32 C6
EPD Power
Environmental Sensor BME688
Voltage Supervisor + Reset & Boot / IO Button
LDO Voltage Regulator
Battery Charge Level
RTC Module DS3231SN
Test Pads
Qwiic / Stemma QT
SPI ESD Protection Lines
External NOR Flash 64MB
OpenBook Schematic
drawn by: Larisa Florea
E-Paper Display Header

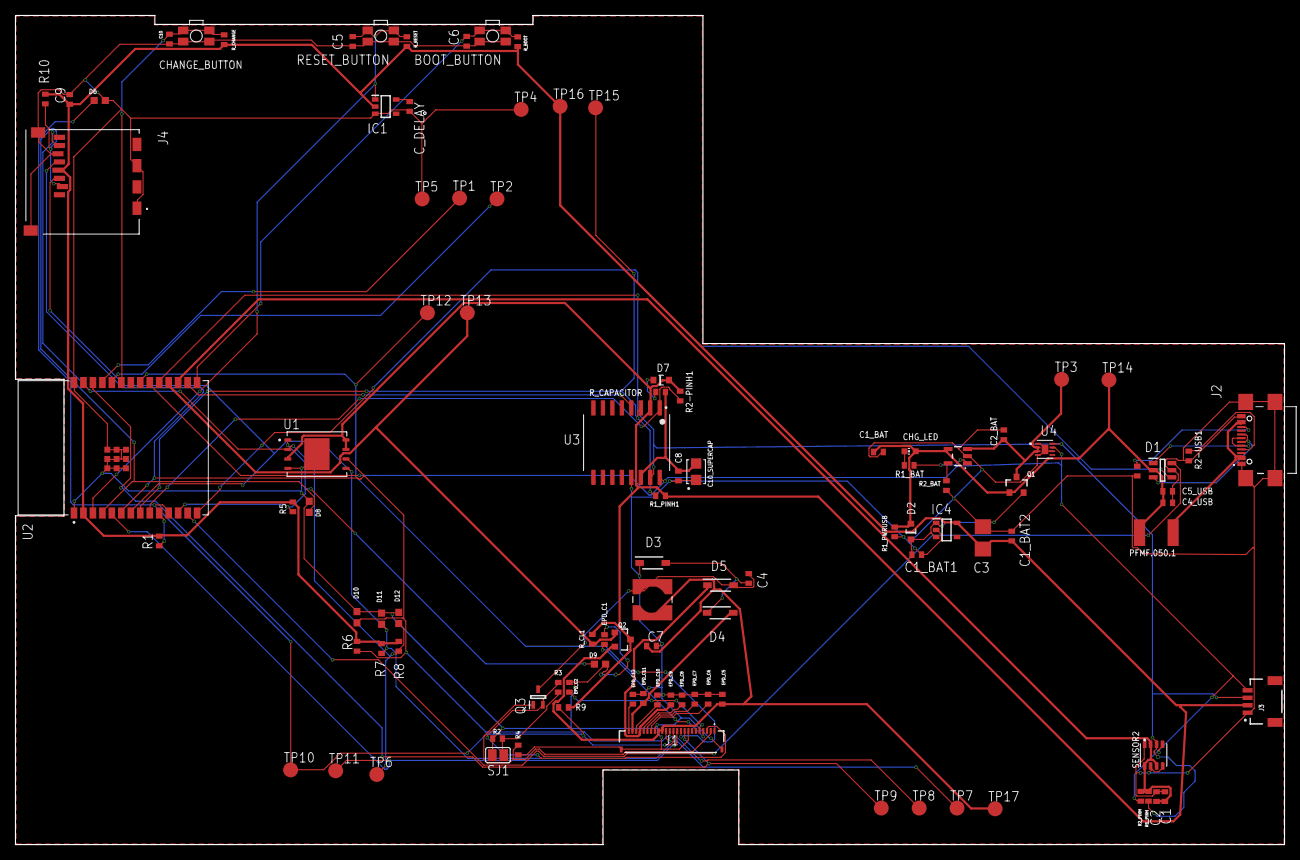
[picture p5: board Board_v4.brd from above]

Board: 2 copper layers, 170.2 x 111.2 mm, 103 parts (0 on the bottom side), 55 nets.

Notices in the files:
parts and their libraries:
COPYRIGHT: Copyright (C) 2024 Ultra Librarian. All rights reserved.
